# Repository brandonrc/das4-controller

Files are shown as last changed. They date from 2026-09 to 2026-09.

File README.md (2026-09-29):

# das4-controller

An open-source replacement controller board for the **Das Keyboard 4 Professional**:
same outline, same holes, same connectors, but with an **RP2350B** you can flash
with your own firmware (pico-sdk today, KMK/CircuitPython, QMK once it supports the RP2350B). It keeps the two USB-A ports (as a USB 2.0
hub), the volume knob, the NUM/CAPS/SCROLL LEDs (now RGB, any colour) and the five buttons. Every
button gets its own GPIO, so you can make them do whatever you like.

> **Status: ready to order after a final 1:1 fit print.** Routed, DRC clean (0 unconnected, 0 real
> violations), with independent circuit and layout reviews, a check against Raspberry Pi's RP2350
> design guide, and a firmware build for this pinout. See [docs/plan.md](docs/plan.md).

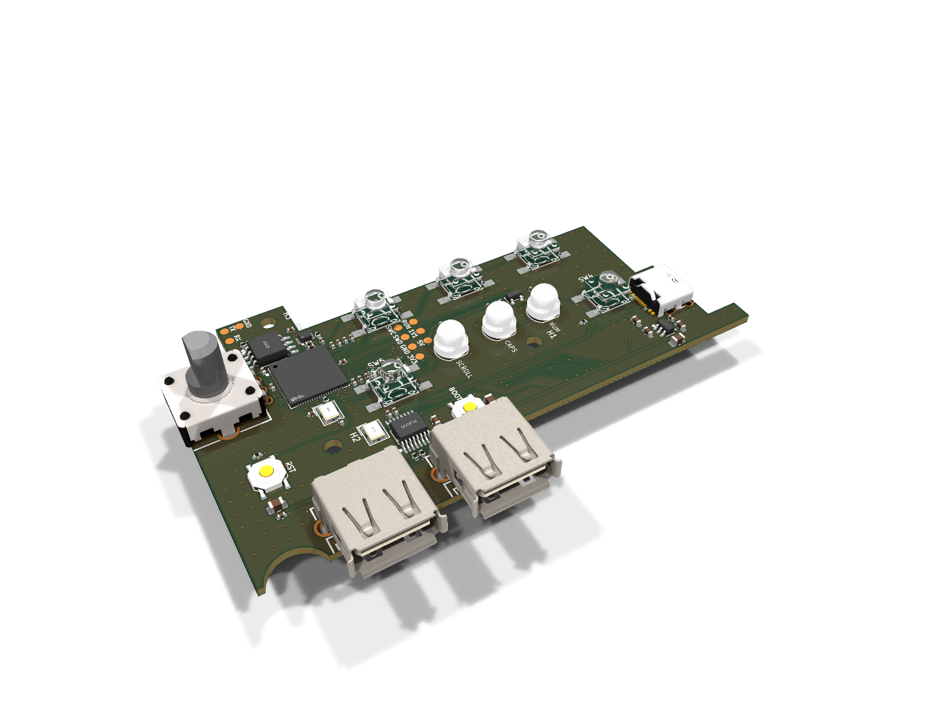
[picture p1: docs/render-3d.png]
3D render


| Top | Bottom |
|---|---|
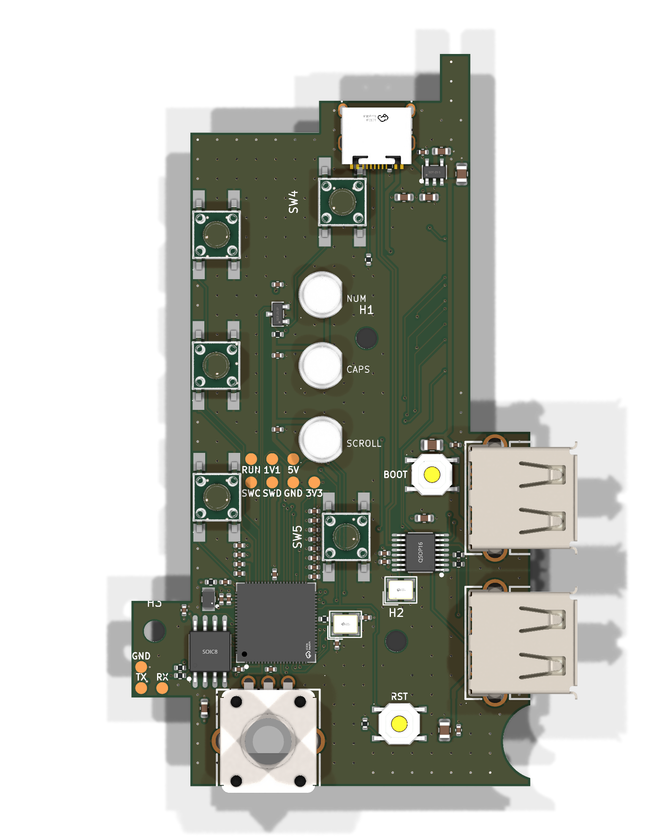
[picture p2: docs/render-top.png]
top
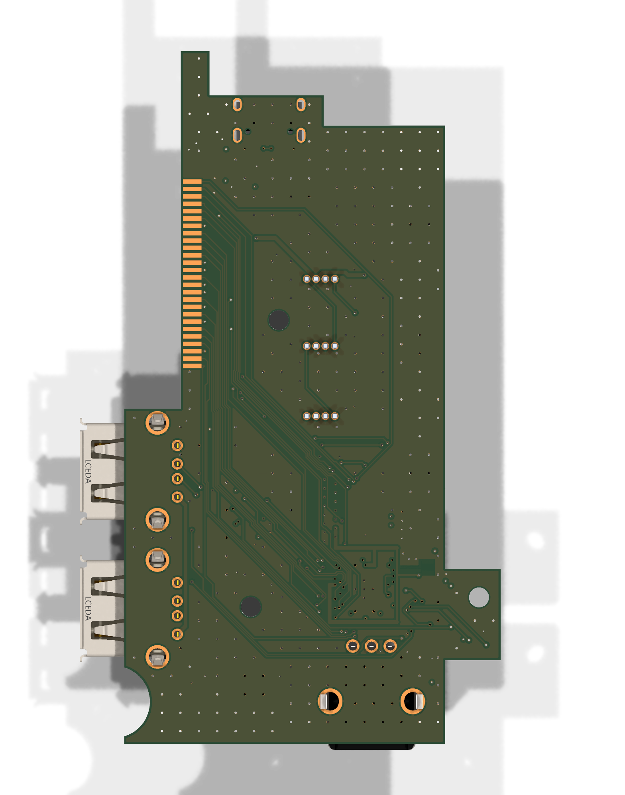
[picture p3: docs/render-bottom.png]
bottom
|  |  |

## Docs

- [Plan and status](docs/plan.md): what's done, next steps, bring-up and firmware plan
- [Design notes](docs/design.md): architecture, circuit blocks, GPIO map, ordering, open questions
- [Bill of materials](docs/bom.md): every part with its LCSC number and live JLCPCB stock
- [Measurements](docs/measurements.md): every dimension, where it came from and how sure we are
- [Fit-check PDF](docs/fit-check-1to1.pdf): print at 100% and lay the original board on it
- Reviews: [circuit](docs/review-2026-09-25.md), [layout 1](docs/review-layout-2026-09-25.md),
  [layout 2](docs/review-layout-2-2026-09-25.md), [RPi design guide](docs/rpi-guide-check-2026-09-26.md),
  [firmware](docs/firmware-check-2026-09-26.md)
- [AGENTS.md](AGENTS.md): how the pipeline works and what to watch out for (for AI agents and humans)

## Layout

```
hardware/
  circuit/das4.py                          the circuit (SKiDL)
  das4-controller.net                      netlist generated from it
  das4-controller.kicad_pro / .kicad_pcb   KiCad 10 project (board generated from the netlist)
  lib/jlc.*                                JLCPCB part symbols, footprints and 3D models (easyeda2kicad)
  lib/das4.pretty                          our own footprints (J4 flex solder pads)
  scripts/gen_board.py                     outline, measured positions, placement, silkscreen
  scripts/critical.py                      hand-drawn critical nets + keep-outs (RP2350 regulator, USB pair, crystal...)
  scripts/route.py, route_best.py          autorouting (Freerouting) + cleanup + GND stitching, best of 6 runs
  scripts/pretest.py, check_layout.py      pre-route DRC of the hand layout; post-route checks
  scripts/jlc_fab.py                       JLCPCB gerber zip, BOM and CPL
  scripts/jlc.py                           search JLCPCB's parts library (no login)
  scripts/bom.py                           docs/bom.md with live stock
docs/                                      notes, plan, reviews, renders, fit-check print
firmware/bringup/                          pico-sdk + TinyUSB bring-up firmware for this pinout
```

## Building

The tools come from the KiBot/KiCad container
[`ghcr.io/inti-cmnb/kicad10_auto_full`](https://github.com/INTI-CMNB/kicad_auto),
which is also what CI runs.

```sh
# one-time: create the container
distrobox create --name pcb --image ghcr.io/inti-cmnb/kicad10_auto_full:1.9.1-1_k10.0.5_d13.2_b4.2.4LTS

distrobox enter pcb -- make pretest       # quick DRC of just the hand layout (run before routing)
distrobox enter pcb -- make board route   # circuit -> netlist -> placed board -> autorouted (~25 min)
distrobox enter pcb -- make check         # post-route checks DRC can't do
distrobox enter pcb -- make docs drc fab  # renders, fit-check PDF, DRC, JLCPCB files (don't rebuild the board)
distrobox enter pcb -- make bom      # refresh docs/bom.md with live JLCPCB stock
```

Or use Docker directly:
`docker run --rm -v $PWD:/w -w /w ghcr.io/inti-cmnb/kicad10_auto_full:1.9.1-1_k10.0.5_d13.2_b4.2.4LTS make`.

Open `hardware/das4-controller.kicad_pro` in KiCad 10 to look around.

**Note:** the board file is *generated*: `make board` rebuilds it (unrouted)
from the circuit and `gen_board.py`, and `make route` routes it. Edit those,
not the .kicad_pcb, or your changes get overwritten.

## Ordering (JLCPCB)

```sh
distrobox enter pcb -- make fab     # -> build/jlcpcb/: gerber zip, bom.csv, cpl.csv
```

1. On jlcpcb.com upload the gerber zip. Pick **4 layers**, 1.6 mm, and the **JLC04161H-7628** stackup with impedance control.
2. Enable **PCB Assembly** (top side), upload `bom.csv` and `cpl.csv`, and check the placement preview:
   rotations, and L1's white dot on the +1V1 pad next to C165 (details in [docs/design.md](docs/design.md#ordering-at-jlcpcb)).
3. Order the "You solder" parts in [docs/bom.md](docs/bom.md) from LCSC (they can ship together).

`make fab` names the zip `...-UNROUTED-quote-only` if the board has no traces yet.

## License

MIT, see [LICENSE](LICENSE). Not affiliated with Das Keyboard / Metadot.

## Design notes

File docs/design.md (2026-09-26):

# Design notes

## Goal

A drop-in replacement for the **Das Keyboard 4 Professional** controller board
(original: `HK-D4215-2-10-03`, 2021-07-27), using an open, reprogrammable MCU.
It must keep the same outline, mounting holes and connector positions, so it
fits the stock case and the stock key-matrix cable.

## What the original board has

| Ref (orig.) | Part | Keep? |
|---|---|---|
| U4 | ~80-pin LQFP MCU, markings removed, 12 MHz crystal | **Replace** with RP2350B |
| U3 | VIA Labs (VLI) USB 3.0 hub | **Replace** with a USB 2.0 hub |
| J5 | USB-C, upstream to the PC | Keep (position) |
| J2, J3 | USB 3.0 Type-A | Keep (position), USB 2.0 is fine |
| J4 | 26-way 1.0 mm flex cable ("CON2") to the key-switch PCB, soldered on (bottom side) | Keep: solder pads, no connector |
| P1 | Rotary encoder, no push switch, 20 detents (5 per quarter turn) | Keep |
| SW1–SW5 | Tact switches | Keep, each on its own GPIO |
| NUM / CAPS / SCROLL | 5 mm THT LEDs | Keep |
| GND/CLK/DIO/5V pads | SWD programming header for U4 | Replace with our own SWD pads |

## Architecture

```
PC ──USB-C──► USB 2.0 hub ──► USB-A port 1
                         ├──► USB-A port 2
                         └──► RP2350B (USB HID keyboard + media keys)
                                 ├─ 26 × key matrix (J4)
                                 ├─ encoder A/B
                                 ├─ 5 × buttons
                                 └─ 3 × RGB lock LEDs (one data line)
```

The PC has to connect to the **hub**, and the MCU hangs off one of the hub's
downstream ports. If the PC plugged into the MCU instead (for example, a
dev board's own USB-C), the USB-A ports would have nowhere to get data from.

## GPIO budget

| Function | Pins |
|---|---|
| Key matrix via J4 (if all 26 are matrix lines) | 26 |
| Encoder: A, B | 2 |
| Buttons | 5 |
| Lock LEDs | 3 |
| **Total** | **36** |

- Seeed XIAO: 11 GPIO, so it doesn't fit.
- Raspberry Pi Pico / Pico 2: 26, so it doesn't fit without an expander.
- **RP2350B: 48, so everything fits on one chip with spare pins.**

The USB hub IC has to be factory-assembled anyway, since it only comes as a
tiny SMD part. So the whole board is factory-assembled (e.g. JLCPCB PCBA)
with a bare RP2350B, not a hand-soldered module.

Fallback: a Pico 2 module plus a 16-bit I²C expander (e.g. TCA9555) for the
buttons and LEDs.

## Circuit

The circuit is code: [`hardware/circuit/das4.py`](../hardware/circuit/das4.py)
([SKiDL](https://github.com/devbisme/skidl)). `make` turns it into a netlist and
places it on the board. The full parts list with live stock is in [bom.md](bom.md).

| Block | Part | Notes |
|---|---|---|
| MCU | RP2350B (QFN-80) | Copied from Raspberry Pi's minimal design: 12 MHz ABM8-272-T3 crystal (15 pF, 1 kΩ), 16 MB W25Q128JV flash, 3.3 µH AOTA-B201610S3R3 inductor for the on-chip 1.1 V regulator (pad 1 to +1V1), 33 Ω/4.7 µF on VREG_AVDD, 100 nF on every IOVDD/DVDD pin. USB series resistors are 22 Ω (JLCPCB Basic) instead of RPi's 27 Ω |
| USB hub | WCH CH334R (QSOP-16) | 4-port USB 2.0, built-in pull-ups/downs. Powered from 3.3 V on both V5 and VDD33 (datasheet §6.1). 12 MHz crystal with no load caps (they're on-chip). Port 1 → USB-A 1, port 2 → USB-A 2, port 3 → RP2350B, port 4 unused |
| 3.3 V | ME6211C33 LDO, 500 mA | ~0.1 V dropout and stable with ceramic caps. An AMS1117 (Basic) was tried and rejected in review: it drops out when VBUS sags on hot-plug, browning out the hub and MCU |
| USB-C | HRO TYPE-C-31-M-12 | 5.1 kΩ on CC1/CC2 (we're a device). No separate ESD chip: the CH334R has 6 kV ESD protection on all its USB pins |
| USB-A ×2 | SHOU HAN AF 90 WJDG (**hand-soldered**) | USB 2.0, right angle, through-hole. VBUS straight from the PC's 5 V (its port limits current); 22 µF + 100 nF per port |
| Encoder | Alps EC12E24204A2 (**hand-soldered**) | 12 mm, no switch, 24 detents, 15 mm D-shaft. A push switch can't fit: the body sits flush with the board edge, so switch pins would land off the board |
| Buttons ×5 | 6 × 6 × 5 mm SMD tact (**hand-soldered**) | Other heights (4.3–10 mm) exist in the same footprint if the case needs them |
| Lock LEDs ×3 | WS2812D-F5 5 mm THT **RGB** (**hand-soldered**) | Any colour from firmware. One GPIO drives the chain NUM → CAPS → SCROLL through a 2N7002 + 1 kΩ pull-up to 5 V (Basic parts): a 5 V-level signal, **inverted**, so firmware inverts the GPIO44 pad output (one register setting; see [firmware-check-2026-09-26.md](firmware-check-2026-09-26.md)). 100 nF per LED |
| BOOTSEL / RESET | TS-1187A 5 × 5 mm SMD tact (JLCPCB Basic) | BOOTSEL via 1 kΩ on QSPI_SS; RESET pulls RUN low through 1 kΩ |
| Test pads | 10, labelled | SWD (SWC, SWD, GND, 3V3, RUN), rails (1V1, 5V), and a UART0 debug console on the left tab (TX = GPIO0, RX = GPIO1, GND) |
| J4 | 26 solder pads, 1.0 mm pitch, 0.6 × 2.5 mm, bottom side at the board edge | The key PCB's flex cable is hot-bar soldered at both ends (no connector), so it's soldered straight onto these by hand, like the original. No part, no cost |

### GPIO map

Picked for routing. Any GPIO can do any job, so firmware just follows this
table ([`das4.py`](../hardware/circuit/das4.py) has the same thing).

| Function | GPIO |
|---|---|
| J4 pin *k* (key matrix) | GPIO(40 − *k*): pin 1 → GPIO39 … pin 26 → GPIO14. Follows the package pin order so the bus fans out without crossings; all on 5 V-tolerant GPIO0–39 |
| SW1 / SW2 / SW3 / SW4 / SW5 (active low, use internal pull-ups) | GPIO45 / 46 / 47 / 43 / 42 |
| Encoder A / B (internal pull-ups) | GPIO13 / GPIO8 |
| RGB LED data (WS2812, chain NUM → CAPS → SCROLL; **inverted**) | GPIO44 |
| UART0 debug console (test pads on the left tab) | GPIO0 TX / GPIO1 RX |
| Spare | GPIO2–7, GPIO9–12, GPIO40–41 |

GPIO40–47 are the ADC pins and aren't 5 V tolerant, which is fine for the
buttons and the LED driver (all 3.3 V). Mind RP2350 erratum E9 on those pins:
use the internal pull-ups, don't rely on pull-downs.

### Board

Stackup: F.Cu signals · In1 solid GND · In2 solid +3V3 · B.Cu signals + GND pour.

The MCU corner follows Raspberry Pi's minimal-design layout, drawn by hand in
[critical.py](../hardware/scripts/critical.py) and locked before autorouting:
- the core regulator block right at pins 61–65: VREG_VIN and +1V1 caps
  against the pins, LX running out between their pads into L1, GND vias
  beside them, and the VREG_AVDD RC filter
- 5 GND vias in the exposed pad, with the solder paste split into 4 windows
  (~50 %) between them so no paste sits over a via
- a via straight inward from every +3V3 pin (to the In2 plane) and every
  +1V1 pin (to a 0.5 mm +1V1 "C" on B.Cu around the chip, like RPi's)
- 100 nF caps in columns beside the pins, with a shared GND via between each
  pair; DVDD pin 10's cap right under the pin
- the crystal right beside XIN/XOUT, with XOUT's series resistor in line and no
  vias or other signals near it
- USB upstream D+/D− as a coupled pair from J1 to the hub over solid GND, kept
  more than 3 mm from the mounting hole; the CC pull-downs
- each tact switch's internally-connected pad pairs joined

Keep-outs (rule areas, from layout review 2):
- no copper on In1, In2 or B.Cu under L1 and VREG_LX (RP2350 datasheet 6.3.8)
- no top-layer pour round the regulator block, so its GND joins main GND at
  one point (the CIN/COUT via pair)
- no top-layer tracks or vias under the USB-A shells
- nothing within 2.5 mm of the mounting holes (screw heads)
- while autorouting only: nothing else through the crystal block

Then Freerouting does the rest (`make route`,
[route.py](../hardware/scripts/route.py)): 4 differently-configured runs in
parallel, best kept. After autorouting: GND stitching vias wherever the outer
pours filled, extra vias into any via-less pour piece, then fill.
Result: 921 track segments, 457 vias; 0 unconnected, 0 non-cosmetic DRC violations.

- **4 layers** (signal / GND / power / signal). The hub's upstream link runs
  at USB high speed (480 Mbit/s) and needs 90 Ω pairs over a solid ground
  plane. The inner layers also make it much easier to fan out the RP2350B's
  0.4 mm pads. At JLCPCB a small 4-layer board costs a few dollars more than
  2-layer.
- **Everything assembled on the top side**, so JLCPCB assembly is
  single-sided. That makes the MCU corner tight: the original put its MCU on
  the back.
- Design rules match JLCPCB 4-layer capabilities with margin (0.1 mm
  clearance, 0.15 mm tracks, 0.5/0.25 mm vias; 0.4/0.2 mm for the vias under
  the MCU).

## Firmware

Checked 2026-09-26 ([firmware-check-2026-09-26.md](firmware-check-2026-09-26.md)):
- **pico-sdk + TinyUSB**: supports everything today. A bring-up firmware for
  this exact pinout builds to a .uf2: [firmware/bringup](../firmware/bringup).
- **KMK / CircuitPython**: works with a small custom board definition and an
  rp2pio-based inverted WS2812 driver. Good for easy hacking.
- **QMK**: no RP2350 support yet (ChibiOS pending; the one proof-of-concept
  fork can't use GPIO above 31, and this board needs up to GPIO47). Nothing
  on the PCB blocks it once support lands.

Flashing: hold BOOTSEL and reset, and the board shows up as a USB drive
(works fine behind the hub). SWD pads as a fallback. Matrix scanning drives
low and reads with pull-ups (never internal pull-downs: RP2350 erratum E9).
The buttons are plain GPIO, so any firmware can give them "fun" functions.

## Ordering at JLCPCB

Files: `make fab` writes `build/jlcpcb/`.
1. Upload `das4-controller-gerbers.zip`. Choose 4 layers, 1.6 mm, and the
   **JLC04161H-7628** stackup with impedance control (the ~90 Ω USB pair
   widths assume it). Vias go down to 0.2 mm drill; pick the matching
   "min via hole" option if the form asks.
2. Turn on PCB Assembly, top side only. Upload `bom.csv` and `cpl.csv`.
3. In the placement preview, check the rotations of U1, U2, J1, L1, Q1, U4,
   Y1 and Y2. **L1's white polarity dot must sit on the +1V1 pad, the end
   next to C165** (Raspberry Pi's layout; the "wrong way round" inductor
   upsets the core regulator). JLC's library model has the dot on pad 2,
   which is +1V1 here, so it should already be right.
4. Hand-solder parts (not in JLC's BOM): 2 × USB-A, the encoder, 3 × WS2812D
   LEDs, 5 × 6 mm tact switches. See [bom.md](bom.md). The J4 flex is
   soldered onto its pads by hand.

## Open questions

- [x] J4 type: a 26-way 1.0 mm flex, soldered at both ends (photos 2026-09-26). The lines all fan into the switch matrix; firmware maps pad *k* to a row or column (a mirrored flex just reverses the table).
- [ ] Does the key PCB have per-key LEDs or diodes? The diode direction sets the scan direction.
- [ ] Encoder: confirm 15 mm shaft / 24 detents is close enough (original: ~14 mm, 20 detents).
- [ ] J4 (for firmware, not the order): unpowered continuity checks on the key PCB: flex pads open to its ground/copper areas; press keys to map rows vs columns; diode mode to see if per-key diodes exist. The key PCB is keys only (no lights), so nothing on it drives the lines.
- [x] Cut JLCPCB fees: 6 Extended types (RP2350B, CH334R, USB-C, inductor, crystal, ME6211 LDO); 11 easy parts are hand-soldered.
- [x] Independent design review: see [review-2026-09-25.md](review-2026-09-25.md).
- [x] Route the board.
- [x] Layout reviews: [review-layout-2026-09-25.md](review-layout-2026-09-25.md), [review-layout-2-2026-09-25.md](review-layout-2-2026-09-25.md).
- [ ] USB-C: only the A4/B9 VBUS pair is wired (B4/A9 boxed in by SW4); fine since plugs tie all VBUS pins.
- [ ] Caliper pass on everything marked *photo* in [measurements.md](measurements.md).
- [ ] Case clearance under the board (bottom side: only the J4 flex now).
- [ ] Order with JLCPCB's JLC04161H-7628 stackup (impedance control), which the ~90 Ω USB pair widths assume.

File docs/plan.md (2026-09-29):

# Plan and status

Last updated 2026-09-29.

## Where we are

**The board is finished and ready to order**, pending a 1:1 fit print in the
case. It's routed, and DRC is clean (0 unconnected, 0 non-cosmetic
violations). CI checks this on every push.

## How we got here

1. **Requirements** (2026-09-24): the same outline, holes and connector
   positions as the original. RP2350B; USB 2.0 hub with 2 × USB-A plus the
   MCU; volume encoder (no push); 5 buttons on their own GPIOs; RGB lock LEDs;
   26-line key matrix.
2. **Measurements:** photos and calipers, then a fit-check print. That fixed
   the USB-A notch (9.35 × 3.5 mm) and the knob position. See
   [measurements.md](measurements.md).
3. **Circuit as code:** SKiDL in `hardware/circuit/das4.py`, with parts
   picked from JLCPCB's library. Extended parts were cut from 15 to 6 to keep
   the order cheap.
4. **Circuit review:** [review-2026-09-25.md](review-2026-09-25.md).
5. **Placement and routing:** generated placement plus Freerouting.
   - First routed board: e51b12c.
6. **Layout review 1:** [review-layout-2026-09-25.md](review-layout-2026-09-25.md).
   - The MCU corner was redone after Raspberry Pi's minimal design: U1
     rotated, the critical nets hand-drawn in `critical.py`, In2 turned into
     a solid 3.3 V plane.
   - Commit 16007bf.
7. **Layout review 2:** [review-layout-2-2026-09-25.md](review-layout-2-2026-09-25.md).
   - Added keep-outs (under L1/LX, the USB-A shells, the screw heads, the
     crystal).
   - DVDD caps, a windowpane paste pattern on the exposed pad, and other
     fixes.
   - Commit f079e2b.
8. **J4:** the key PCB's flex cable is soldered at both ends (photos,
   2026-09-26), so J4 became 26 solder pads at 1.0 mm pitch. There's no
   connector, and the lines are keys only, with no 5 V.
9. **Checked against Raspberry Pi's "Hardware design with RP2350":**
   [rpi-guide-check-2026-09-26.md](rpi-guide-check-2026-09-26.md).
   - The circuit matches their reference.
   - A cap was added at DVDD pin 51.
   - L1's orientation was confirmed.
10. **Firmware check:** [firmware-check-2026-09-26.md](firmware-check-2026-09-26.md).
    - pico-sdk + TinyUSB builds for this pinout (`firmware/bringup`).
    - KMK/CircuitPython works with a custom board definition.
    - QMK has no RP2350 support yet.
    - UART debug pads were added on the strength of this check.

## Next steps

1. **Fit print (owner):** print `docs/fit-check-1to1.pdf` at 100 % (Actual
   size) and lay it in the case. Check the J4 pad strip against the flex, the
   USB-C/USB-A mouths, the 3 mounting holes, the knob and the buttons.
2. **Order at JLCPCB.** Follow "Ordering at JLCPCB" in [design.md](design.md):
   - 4 layers, JLC04161H-7628 stackup with impedance control
   - top-side assembly with `bom.csv` and `cpl.csv`
   - check L1's dot and the rotations in the placement preview
   - order the hand-solder parts from [bom.md](bom.md)
3. **Hand-solder:** USB-A ×2, encoder, WS2812D ×3, 6 mm switches ×5, and the
   J4 flex onto its pads.
4. **Bring-up** (see below).
5. **Keyboard firmware** (see below).

## Bring-up plan

Do it in this order, and stop at the first surprise.

1. **Before power:** look for solder bridges, especially at U1 (0.4 mm pitch)
   and the hub. Check the ohms from 5V, 3V3 and 1V1 to GND: none should be a
   short.
2. **First power**, from USB-C, ideally through a current-limited USB meter.
   Use the test pads:
   - **5V:** about 5 V
   - **3V3:** 3.3 V
   - **1V1:** about 1.1 V, from the RP2350's internal regulator
3. **The hub** should enumerate on the PC as a USB 2.0 hub. Test both USB-A
   ports with a USB stick.
4. **Hold BOOT and tap RST:** an RP2350 drive should appear. If it doesn't,
   use the SWD pads (SWC, SWD, GND) with a Raspberry Pi Debug Probe.
5. **Flash `firmware/bringup`:**
   - it should enumerate as a USB keyboard
   - the LEDs should light
   - SW1 should respond
   - a USB-serial adapter on TX/RX/GND (115200 baud) shows `printf` output
     even if USB fails
6. **Map the key matrix:** press keys and log which J4 lines connect, to get
   rows vs columns and whether the key PCB has diodes. Unpowered continuity
   checks on the key PCB work too.

## Firmware plan

1. **pico-sdk + TinyUSB keyboard**, built from `firmware/bringup`:
   - matrix scan with debounce and ghost-key handling (if the key PCB has no
     diodes), and a keymap
   - media keys on the encoder and the 5 buttons
   - lock-LED report onto the RGB LEDs (red by default, changeable)
2. **Later:** port to QMK/Vial once QMK supports the RP2350B, including
   GPIO above 31. Nothing on the PCB blocks that. KMK/CircuitPython is an
   option for easy hacking in the meantime.

## Known deviations (accepted)

- The USB 22 Ω resistors sit at the hub end, not at the RP2350. It works at
  12 Mbit/s; the guide prefers 27 Ω close to the chip.
- DVDD pin 32's nearest cap is about 11 mm away, because there's no room
  beside it.
- A few vias touch same-net pads (SW3 GND, TP8), which is harmless.
- Some footprints' own silkscreen outlines touch pads; JLC trims them.

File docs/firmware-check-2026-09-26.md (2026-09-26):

# das4-controller: firmware readiness check (2026-09-26)

## Verdict

**Yes, with caveats. No hardware change is required before ordering.**

- **pico-sdk + TinyUSB** supports every pin and feature on this board today. A test firmware using this exact pinout builds to a `.uf2` (see Build).
- **CircuitPython/KMK** also works, but it needs a small custom board definition and a custom inverted PIO LED driver.
- **QMK cannot target this board today.** It has no RP2350 support in master or develop. The only RP2350 port is an out-of-tree proof of concept, and it explicitly does not support RP2350B GPIO above 31. This board uses GPIO32–47 for 8 matrix lines, all 5 buttons and the LED.
- **No pin swap can fix the QMK problem.** The board needs 36 signals, but only 32 GPIO (0–31) exist below GPIO32.
- **One doc error to fix.** `docs/design.md` says to use QMK `WS2812_EXTERNAL_PULLUP` for the inverted LED line. That is wrong for this circuit (details in the table notes).

## Firmware options × requirements

| Requirement | pico-sdk 2.3.1 + TinyUSB | CircuitPython 10.3.1 + KMK | QMK (master/develop, 2026-09-26) | QMK POC branch `emolitor/em-rp2350` (2026-07-22) |
|---|---|---|---|---|
| RP2350B (QFN-80) | ✅ `PICO_RP2350A=0`. Stock example: `pimoroni_pga2350.h` (RP2350B + 16 MB) | ✅ `CHIP_PACKAGE = B`. Example: `adafruit_metro_rp2350` (RP2350B, W25Q128JV) | ❌ No RP2350 at all. Schema lists only `RP2040`. Issue #25881 was closed "not planned" pending ChibiOS | ⚠️ RP2350**A** pinout only |
| GPIO30–47 | ✅ `gpio_get_all64()`. PIO uses `GPIOBASE=16`, which the SDK handles automatically (`pio_claim_free_sm_and_add_program_for_gpio_range`) | ✅ `microcontroller.pin.GPIO32…47`. rp2pio computes the GPIO base | ❌ | ❌ "GPIO banks above 31 … not yet supported" |
| 16 MB flash | ✅ `PICO_FLASH_SIZE_BYTES`, `boot2_w25q080` | ✅ `EXTERNAL_FLASH_DEVICES = "W25Q128JVxQ"` | ❌ | ⚠️ `RP_FLASH_SIZE` override (default 4 MB) |
| Inverted WS2812 | ✅ Standard PIO program plus `gpio_set_outover(44, GPIO_OVERRIDE_INVERT)`. Built and verified here | ⚠️ `neopixel_write` can't invert. Use `rp2pio.StateMachine` with the ws2812 program's side-set values swapped and `initial_sideset_pin_state=1`, then pass it to KMK's RGB extension via `pixels=`. Or set OUTOVER through `memorymap` | ❌ `WS2812_EXTERNAL_PULLUP` is open-drain and **non-inverting** (side-set on pindirs). On this 2N7002 gate it would leave the LEDs stuck. You'd have to patch in `PAL_RP_IOCTRL_OUTOVER_DRVINVPERI` | ❌ (pins) |
| Encoder (GPIO13/8, pull-ups) | ✅ Write it yourself (quadrature state table) or use a PIO quadrature example | ✅ `kmk/modules/encoder.py` | (✅ on RP2040) | ❌ (pins ≥32 elsewhere) |
| 26-line matrix + direct pins | ✅ Write it yourself (example included). 26 lines fit in one `gpio_get_all64()` read | ✅ `keypad.KeyMatrix` / KMK `keypad` scanner. **Pass the anode-side lines as columns and keep `columns_to_anodes=True`**: `False` switches to pull-downs, which E9 affects | (✅ on RP2040) | ❌ |
| UF2 / BOOTSEL | ✅ ROM bootloader. `picotool reboot -f -u` via `pico_usb_reset_interface` | ✅ | ❌ | ✅ `bootloader: rp2350`, `QK_BOOT` |

**Recommendation: pico-sdk + TinyUSB now.**
- It's the only path that fully covers RP2350B today, and it has already been built here.
- A keyboard is roughly 500 lines on top of the test firmware: matrix, debounce, keymap, HID with NKRO and consumer keys, lock-LED output report, encoder.
- CircuitPython/KMK is a good second choice for quick hacking. It supports the chip; it just needs a board definition without the Metro's status NeoPixel on GPIO25 and PSRAM chip-select on GPIO47 (both are pins this board uses) and the inverted LED driver.
- Move to QMK/Vial once QMK adds RP2350B GPIOBASE support. Nothing on the PCB blocks that; it's purely a software gap.

## Flashing and bring-up

- **BOOTSEL wiring is correct.** It's QSPI_SS → 1 kΩ → button → GND, with a 10 kΩ pull-up (about 0.3 V when pressed), the same as RPi's reference.
  - The bootrom enters BOOTSEL when QSPI CSn is low at reset (datasheet §5.2).
  - It picks USB rather than UART boot because QSPI SD1 is not driven high. SD1 has a default pull-down, and the W25Q128 DO pin is high-Z with no command.
  - Hold BOOTSEL, press RUN, and it enumerates as the RP2350 UF2 drive / picotool device.
- **Behind the CH334R hub: no issue.**
  - The RP2350 is a full-speed device. The CH334R is a multi-TT high-speed hub, so the FS device is handled by the hub's transaction translator, which is normal.
  - The ROM bootloader and TinyUSB don't care about a hub.
  - The RP2350 has no VBUS pin; the SDK and TinyUSB force VBUS-detect in software.
  - After the first flash, the BOOTSEL button isn't needed: `picotool reboot -u`, or a firmware key calling `rom_reset_usb_boot()`, gets back to the bootloader.
- **SWD is a usable fallback.** Pads TP1–TP5 (SWCLK, SWDIO, GND, 3V3, RUN) work with a Raspberry Pi Debug Probe or a Pico running debugprobe, plus RPi's OpenOCD fork (`target/rp2350.cfg`, full support) or upstream OpenOCD master (Arm cores).
- **12 MHz** is the SDK default: `XOSC_HZ 12000000` in `rp2350/.../platform_defs.h`. The bootrom's USB PLL also assumes 12 MHz unless OTP says otherwise (datasheet §5.2).
- **Board header needed** (`boards/das4_controller.h`, modelled on `pimoroni_pga2350.h`):
  - `PICO_RP2350A 0`
  - `PICO_FLASH_SIZE_BYTES (16*1024*1024)`
  - `PICO_BOOT_STAGE2_CHOOSE_W25Q080 1`
  - `PICO_FLASH_SPI_CLKDIV 2`
  - `PICO_PLATFORM rp2350` (arm-s)
  - As a shortcut, `-DPICO_BOARD=pimoroni_pga2350` also works as-is. The RP2350 has no separate boot2 stage like the RP2040; the SDK embeds an IMAGE_DEF block for the bootrom.

## Build attempt: succeeded

The host had git and g++ but no cmake or arm-none-eabi-gcc (the `pcb` distrobox has neither). Everything was installed in the scratchpad in about 5 minutes:

```sh
cd scratchpad/fw
python3 -m venv venv && ./venv/bin/pip install cmake ninja        # cmake 4.4.3
git clone --depth 1 https://github.com/raspberrypi/pico-sdk.git   # SDK 2.3.1 (079c6f3, 2026-09-04)
git -C pico-sdk submodule update --init --depth 1 lib/tinyusb
curl -L https://developer.arm.com/-/media/Files/downloads/gnu/15.2.rel1/binrel/arm-gnu-toolchain-15.2.rel1-x86_64-arm-none-eabi.tar.xz | tar xJ
./build.sh     # PICO_SDK_PATH/PICO_TOOLCHAIN_PATH; cmake -G Ninja; ninja  (picotool auto-fetched and built)
```

Result: `fw/build/das4fw.uf2` (39 KB), 0 warnings. `picotool info -a` reports family `rp2350-arm-s`, `pico_board: das4_controller`, `boot2_w25q080`, SDK 2.3.1. Compile-time asserts check `NUM_BANK0_GPIOS == 48` and `PICO_FLASH_SIZE_BYTES == 16 MB`.

What the test firmware (`fw/das4fw/`) does:
- Enumerates as a TinyUSB HID keyboard.
- Scans an 8×18 placeholder split of GPIO14–39: drives lines low one at a time and reads the others with pull-ups.
- Reads SW1 on GPIO45 (pull-up) and sets pull-ups on the encoder pins GPIO13/8.
- Drives 3 × WS2812 on GPIO44 with the standard PIO program and pad-level output inversion. PIO idles low, so the pad sits high, the FET is on, and DIN is held low (the WS2812 reset state).

Not tested on hardware (there is no board yet).

## Hardware checks

- **E9 (datasheet build 2025-07-29, p.1366):**
  - What it is: on **A2** silicon, an input-enabled pad sitting between VIL and VIH leaks about 120 µA and latches near 2.2 V, which beats the internal pull-down. Pull-ups work normally.
  - Status: fixed in A3/A4 silicon ("Fixed by RP2350 A3"). The workaround is to avoid internal pull-downs, or use an external pull-down of 8.2 kΩ or less.
  - JLC's C42415655 (4,271 in stock) doesn't state the stepping. The design doesn't depend on it; at runtime, `rp2350_chip_version()` reports it.
  - Matrix: always scan by driving low and reading with pull-ups. With diodes, drive the cathode-side lines and read the anode side; either diode direction can be scanned this way, so the unknown row/column split doesn't matter. Without diodes, E9 isn't a factor either, but ghosting is: firmware must block ghosts.
  - Buttons (pull-ups, active low) and encoder (common to GND, pull-ups): unaffected.
  - The LED gate relies on the power-on pull-down, which E9 doesn't affect: it only applies once IE is set, and firmware drives the pin by then.
- **ADC pins as digital inputs:** GPIO40–47 are ordinary digital I/O that also have the ADC. Digital input works once `gpio_init` sets IE and clears ISO; the SDK and CircuitPython do this. Just don't enable their ADC channels. They are **not** 5 V tolerant (VPIN ≤ IOVDD + 0.5 V), and nothing on them exceeds 3.3 V: buttons to GND, and the 2N7002 gate.
- **5 V tolerance:** J4 is on GPIO14–39, which are FT pins (up to 5.5 V with IOVDD at 3.3 V). The key PCB is passive, so it's moot anyway.
- **LED level shifter timing:** the 1 kΩ pull-up with about 40 pF gives about 50 ns to reach 0.7·VDD. That shortens each DIN high pulse by about 50 ns. A 0-bit is then about 325 ns high, still inside WS2812D T0H (220–380 ns). Fine.

## Hardware changes before ordering

**Required: none.**

Optional, cheap, and useful:
1. **Put GPIO0/GPIO1 (spare, UART0 TX/RX) on two test pads.** This gives a debug console during bring-up that doesn't depend on USB enumeration. It's the only change I'd actually make.
2. **Only if you want unpatched QMK/KMK LED drivers someday:** replace the 2N7002 + 1 kΩ inverter with a non-inverting 5 V buffer, e.g. 74AHCT1G125 (VCC 5 V, OE to GND). Not needed: pad inversion is one register write in every framework.

Doc fix (not hardware): in `docs/design.md`, replace "QMK: `WS2812_EXTERNAL_PULLUP`" with "invert the pad output (`IO_BANK0 GPIO44_CTRL.OUTOVER = INVERT`)". Also note that QMK doesn't yet support RP2350B.

## Sources (fetched 2026-09-26)

- RP2350 datasheet, build-date 2025-07-29: E9 p.1366–1367, A3 changes, pin types/FT §14.8.2, BOOTSEL/UART boot §5.2/§5.8. https://datasheets.raspberrypi.com/rp2350/rp2350-datasheet.pdf
- A4 stepping / E9 fix: CNX Software 2025-07-29, https://www.cnx-software.com/2025/07/29/raspberry-pi-rp2350-a4-stepping-fixes-e9-gpio-erratum-9-glitching-bugs-introduces-2mb-flash-variants/ ; Hackaday 2025-07-31, https://hackaday.com/2025/07/31/raspberry-pi-rp2350-a4-stepping-addresses-e9-current-leakage-bug/
- pico-sdk 2.3.1 (2026-09-04): https://github.com/raspberrypi/pico-sdk (`pimoroni_pga2350.h`, `hardware_pio` GPIOBASE, `platform_defs.h`)
- QMK master b1aea25 / develop 5060d75 trees (2026-09-26), no RP2350 files: https://github.com/qmk/qmk_firmware ; issue #25881 (comments to 2026-07-22): https://github.com/qmk/qmk_firmware/issues/25881 ; QMK `ws2812_vendor.c` (develop): https://github.com/qmk/qmk_firmware/blob/develop/platforms/chibios/drivers/vendor/RP/RP2040/ws2812_vendor.c
- QMK RP2350 POC `docs/platformdev_rp2350.md` (2026-07-22): https://github.com/emolitor/qmk_firmware/blob/em-rp2350/docs/platformdev_rp2350.md
- ChibiOS RP2350 commit 532dcc8 (2026-01-18); latest tag still ver21.11.5: https://github.com/ChibiOS/ChibiOS
- CircuitPython 10.3.1 (2026-09-14); `rp2pio/StateMachine.c` GPIO-base handling; `adafruit_metro_rp2350` board; `shared-module/keypad/KeyMatrix.c`: https://github.com/adafruit/circuitpython ; rp2pio docs: https://docs.circuitpython.org/en/latest/shared-bindings/rp2pio/index.html
- KMK main (2026-04-09): `kmk/extensions/rgb.py` (`pixels=`), `kmk/modules/encoder.py`: https://github.com/KMKfw/kmk_firmware
- OpenOCD RP2350: https://github.com/raspberrypi/openocd/blob/sdk-2.0.0/tcl/target/rp2350.cfg ; https://review.openocd.org/c/openocd/+/8449
- JLCPCB part C42415655 stock (API, 2026-09-26): https://jlcpcb.com/partdetail/C42415655
- Arm GNU Toolchain 15.2.rel1: https://developer.arm.com/downloads/-/arm-gnu-toolchain-downloads

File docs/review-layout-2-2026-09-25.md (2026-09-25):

# Layout review 2: das4-controller (board as of 16007bf, 2026-09-25)

Method: I copied the board to the scratchpad, refilled the zones, and ran pcbnew scripts plus kicad-cli DRC. I rendered each layer and checked the regulator section against the RP2350 datasheet (section 6.3.8, "External components and PCB layout requirements") and "Hardware design with RP2350". Coordinates are board mm (origin 100,150, +Y up).

DRC: 0 unconnected. 6 errors: 3 starved thermals (Y2.2, Y2.4, J2.4 on B.Cu), and 3 malformed courtyards on D1–D3, which means those three LEDs are silently left out of the courtyard-overlap check. 59 silkscreen warnings.

## Verdict: **fix first**

The MCU corner rework dealt with most of the first review. Three things still stop this going to the fab:
- J4 is still a placeholder.
- The regulator ignores a "must" in the RP2350 datasheet: the inner planes run solid under L1 and VREG_LX.
- VBUS and key-matrix traces run under the grounded USB-A shells.

Everything else is cheap to fix while you're in there.

## Previous review: status

| # | Finding (review 1) | Status | Evidence now |
|---|---|---|---|
| B1 | EP has no GND vias | **Resolved** | 3×3 array of 0.5/0.25 vias in U1.81, straight into the solid In1 |
| B2 | Regulator ignores RPi layout | **Partial** | C164 (CIN) is 1.2 mm from pins 64 and 62. C165 (COUT) is next to L1.2 (1.8 mm). FB is a Kelvin tap at C165+ (2.8 mm), not under L1. C161 has its own GND via. **But** there's no plane cut-out under L1/LX, RUN runs under L1, and LX is a 0.15 mm trace under the L1 body (see Blockers) |
| B3 | USB_UP not a pair | **Resolved** | Coupled on F.Cu, 0.25/0.15 mm, ≈86–90 Ω on JLC04161H-7628 once solder mask and the 0.25 mm coplanar pour are allowed for. Centreline over solid In1 the whole way. Only vias are the D− hop at J1. D+ 56.0 mm vs D− 54.5 mm (≈10 ps). At least 3.2 mm from H1 |
| B4 | J4 is a placeholder | **Not resolved** | Still `PinSocket_1x26_P1.00mm_Vertical` on B.Cu; design.md says pitch and type are unknown |
| S | +3V3 only on 0.15 mm traces | **Resolved** | In2 +3V3 is one piece covering 81 % of the board (In1 GND covers 90 %) |
| S | MCU decoupling 7–14 mm away | **Partial** | Pins 5, 41, 59, 60 and 64 have caps right at the pin. IOVDD pins 15, 24, 29, 50, 68, 69 and 76 reach their caps only through a via, the In2 plane and 8–20 mm of distance. DVDD pins 10, 32 and 51 are 15.5, 24 and ≈12 mm of trace from the nearest +1V1 cap |
| S | USB_MCU_D− 0.1 mm from L1 | **Resolved** | USB_DP/DM now leave inward and run on B.Cu under the chip |
| S | Y1 crystal traces long | **Partial** | XIN is 4.9 mm and XOUT 6.4 mm, no vias. **But** the autorouter put KM18 through C230's and C231's pad gaps, and KM15/KM16 vias sit 0.2–0.5 mm from XIN/XOUT (see Should fix) |
| S | +5V 0.3 mm | **Resolved** | 0.5 mm everywhere (0.375 mm into C12). About 50 mΩ from J1 to J2, 70 mΩ to J3 |
| S | Vias inside pads | **Partial / worse** | Now 22 vias touch pads: 20 shared decoupling GND vias each overlap two 0402 pads by 0.01 mm; Y1.2 by 0.05 mm, Y2.2/Y2.4 by 0.09 mm, L1.2 is 0.008 mm off the pad; plus 9 open vias in the EP |
| S | Hub decoupling far; GND pin 14 on 0.112 mm | **Partial** | C6/C7 are within 1.5 mm of pins 12/13, but connect through plane vias rather than directly. Pin 14 still leaves on a 0.112 mm neck, though pour spokes now also reach it |
| S | USB_A1 under J2's shell, pair splits layers | **Not resolved** | Each line still has a via to B.Cu. On B.Cu the two lines are 1.4 mm apart (uncoupled, ≈125 Ω diff) and referenced to the 3V3 plane. Mismatch 3.4 mm (D− 11.5, D+ 8.1); D− hooks round the D+ via at (33.1–33.9, 35.5) |
| N | Single-spoke thermals | Partial | Y2.2, Y2.4 and J2.4 (B.Cu) are starved |
| N | Silkscreen | Not | 23 silk-over-copper. The **U1** label sits on U3 (2.1, 21.0), **U3** on L1, **L1** over U1 pins 62–65, **Y2** over U2 pins 12/13, **TP1** over TP5 |
| N | WS2812 pads 1.27 mm / 0.22 mm gap | Not | Footprint unchanged |
| N | Define the JLC stackup | Not | The .kicad_pcb has no `(stackup)` section |
| N | USB-C VBUS/GND pads 0.1 mm apart | Not | Footprint unchanged (stock HRO footprint; acceptable) |

## New findings

### Blocker

1. **Solid planes under L1 and VREG_LX, and a signal under L1** (L1 at 2.34, 24.0)
   - **What the datasheet says** (§6.3.8.1): "For a multi-layer board (4 or more layers) please cut away any copper immediately underneath L/VREG_LX". It also says to cut copper under the inductor on the top layer, and that "these guidelines must be strictly followed".
   - **What I measured:**
     - In1 GND is 96 % filled under the L1 body and 100 % under the LX strip. In2 +3V3 is 93 % and 100 %.
     - RUN runs on B.Cu at x = 1.9–2.3 mm, from y 19.1 to 30.2, i.e. right under L1.
     - The +1V1 spine on B.Cu (x = 3.2 mm, 0.5 mm wide) also runs under L1.
   - **Fix:**
     - Add a keep-out rule area (tracks, vias, pours) on In1, In2 and B.Cu covering L1 plus about 0.3 mm, and the LX trace from pin 63 to L1.1.
     - Move RUN out of that area. The +1V1 spine can start at the via (3.35, 22.35) heading away from L1.
     - After the change, check the In2 3V3 path to pin 64 still exists.

2. **J4 footprint unknown** (carried over): don't order until the connector pitch, type and position are confirmed. The 26 key-matrix nets are the board's reason to exist.

3. **VBUS and key-matrix traces under the USB-A metal shells**
   - **Measured:** F.Cu length inside the J3 courtyard: **+5V 13.5 mm** (x = 37.49, y 16–22.6, between the pin row and the shell tabs). Inside J2: KM26 13.4 mm, KM23 11.1 mm, +5V 4.0 mm.
   - **Risk:** the shell is GND and sits on the solder mask. One scuff shorts the host's VBUS to GND, or a matrix line to GND.
   - **Fix:** keep-out on F.Cu over both shell footprints (x > 35.4 inside the J2 and J3 courtyards). Route +5V from J2.1 to J3.1 on B.Cu, on the x < 35.3 side. Move KM23 and KM26 off that area.

### Should fix

1. **DVDD decoupling and the second 4.7 µF**
   - **Measured:** 100 nF caps C110, C132 and C151 sit in a column at x = 15.9, y 28–30. Trace paths from DVDD pins 10, 32 and 51 are about 32, 24 and 12 mm, much of it the 0.5 mm B.Cu spine. C166 (the second COUT) is 25–35 mm of trace from every DVDD pin.
   - **Guidance:** RPi wants 100 nF at every power pin, and the second 4.7 µF "on the bottom edge of the package", away from LX/COUT.
   - **Fix:**
     - Put a 100 nF at pin 10 (≈10.8, 15.2; there's a 1.4 mm strip between U1 and the ENC1 courtyard) with C166 beside it.
     - Put one at pin 32, on the right side, when rerouting around Y1.
     - Same idea for IOVDD: pins 15, 24 and 29 have no cap within 6.5 mm.

2. **Key-matrix lines through the crystal block**
   - **Measured:**
     - KM18 (F.Cu) runs at y = 18.3 between C230's pads, 0.125 mm from each.
     - It then goes up x = 22.50, between C231's pads, 0.8 mm from Y1.3.
     - The KM15 via at (17.20, 22.44) is 0.19 mm from the end of the XOUT trace; the KM16 via at (17.32, 19.99) is 0.46 mm from XIN.
   - **Fix:** F.Cu keep-out over Y1, C230, C231 and R231 plus 0.5 mm, then reroute KM18 on B.Cu (In1 shields it there).

3. **Regulator GND should join main GND at one point** (datasheet: "only connect to main GND at one point").
   - **Measured:** the C164/C165 GND pads are tied to the F.Cu pour by thermal spokes (0.19/0.15 mm² of overlap), in addition to their two vias at (3.99/4.93, 25.1).
   - **Fix:** F.Cu pour keep-out around the C164/C165/L1 block, so that CIN/COUT GND reaches main GND only through that via pair.

4. **LX trace**
   - **Measured:** 0.15 mm wide, 4.75 mm long.
   - **Route:** it runs between both caps' pads with 0.125 mm clearance, then 1 mm under the L1 body into pad 1 from below.
   - **Fix:** make it 0.3–0.4 mm and bring it into L1.1 from outside the body. Rotating or moving L1 so pad 1 faces pin 63 would make this simpler.

5. **EP paste and vias**
   - **Measured:** U1.81 paste is one 3.4 × 3.4 aperture (100 % coverage) over 9 untented, unplugged 0.25 mm vias. That means voids and solder wicking, and on a 0.4 mm pitch QFN, a risk that the part floats and opens pins.
   - **Fix:** a 2×2 or 3×3 windowpane at 50–65 % coverage that sits between the vias. Alternatively order via-in-pad epoxy-filled and capped.

6. **Vias overlapping pads**
   - **Measured:** the 20 shared GND vias in the decoupling columns (x = 16.38 and x = 5.82) each overlap two pads by 0.01 mm. That leaves a mask tent of about 0.31 mm over a 0.2 mm hole.
   - **Fix:** move each via 0.35 mm outboard of the pad ends (x ≈ 16.75 / 5.45) with a short neck. Pull the Y1.2 via at (21.90, 19.95) out to x ≥ 22.1, and the Y2 vias at (28.93, 23.71) and (25.07, 26.69) likewise.

7. **Signals under the mounting-hole screw heads**
   - **Measured:** non-GND copper 0.3–0.9 mm from the 2.7 mm hole edge.
     - H1: KM10/KM11 on B.Cu at 1.65–1.94 mm from the hole centre.
     - H2: KM13, KM21 and KM23 at 1.65–1.8 mm.
   - An M2.5 head or standoff is about 4.5–5 mm across, so these traces sit under the metal.
   - **Fix:** a round keep-out of radius 3 mm on F.Cu and B.Cu around H1–H3. A plated GND ring is optional.

8. **USB_A1**
   - **Fix:** route +5V to J2.1 on B.Cu (or from the outside). That frees F.Cu so D± can run as a coupled 0.2/0.12 pair straight to J2.2/J2.3, like USB_A2 (which is fine at ≈90 Ω, 1.5 mm mismatch). That drops both vias and the 3.4 mm skew.

### Nice to have

- **Foreign vias beside USB_UP:** the KM20 via at (26.88, 50.32) is 0.16 mm from USB_UP_D−, and its In1 anti-pad eats under the trace edge. The KM9 via at (25.27, 60.16) is 0.3 mm from D+. Move both at least 0.75 mm clear.
- **R266/R267** (22 Ω) sit at the hub, 30 mm from the RP2350. The guide says to put them "close to RP2350". It doesn't matter electrically at 12 Mbit/s, but it's the documented rule.
- **LDO:** U4.5 (+3V3) reaches the plane through a single 0.45/0.2 via at (29.75, 80.70). The output caps C4/C5 are 4–5 mm away through the planes. Add 2 more vias and put C4 right at pin 5.
- **Stackup:** add JLC04161H-7628 to the board setup and choose it (with impedance control) on the order form. Otherwise the ≈90 Ω pair widths are only an assumption.
- **Vias:** 94 vias have 0.2 mm drills. Pick JLC's matching "min via hole" option and check whether it adds cost. Everything else is well inside JLC's 4-layer limits: minimum track 0.112 mm, clearance 0.10 mm, annular ring ≥ 0.1 mm, copper ≥ 0.3 mm from the edge.
- **D1–D3 courtyards:** fix them so the courtyard checks run on the LEDs.
- **Silkscreen:** move the refdes labels listed above. Don't rely on the silk for L1's dot; confirm the polarity in JLC's DFM/placement preview. The footprint's r = 0.13 dot is at pad 2 = +1V1, as the circuit review intended.
- **Test points:** add pads for +1V1 and +5V, to check the regulator at bring-up.
- **B4A9:** the USB-C VBUS pad B4A9 is left floating. Tie it to +5V if routing allows.
- **CPL/BOM** (build/jlcpcb, which is current):
  - All 58 assembled parts are present; the hand-solder parts are correctly left out.
  - Gerbers and drill files share the aux origin (100, 150), consistent.
  - The BOM comment for SW6 reads "RESET" (it's BOOTSEL); cosmetic only.
  - Check rotations for U1 (90), U2 (90), J1 (180), L1 (270), Q1, U4 and Y1/Y2 in JLC's preview.

## Verified OK
- In1 is solid GND under every USB and crystal centreline.
- Stitching vias are about 2.5 mm apart.
- Main VREG loop: CIN at the pins and COUT at L1, both returning to PGND in about 2 mm.
- The FB Kelvin tap is not under L1.
- The VREG_AVDD RC has its own GND via.
- Flash: QSPI traces are ≤ 10 mm with only 2 vias (SD2/SD3). The pull-up and BOOTSEL resistors sit at U3.
- CC pull-downs are fine.
- USB_A2 pair is fine.
- The +5V trunk is 0.5 mm.
- The encoder frame is tied to GND.

## Follow-up (same day)

Addressed in the next commit, board re-routed: 0 unconnected, 0 non-cosmetic DRC violations in all 4 router variants.

| Finding | Done |
|---|---|
| Blocker 1: planes/signals under L1 and LX | Rule area: no copper on In1, In2 or B.Cu under L1 or along LX. The +1V1 spine now leaves under U1's left pad row, and RUN is routed elsewhere |
| Blocker 2: J4 | **Open**: waiting on the connector's pitch, type and photos |
| Blocker 3: under the USB-A shells | Rule area: no F.Cu tracks or vias under either shell |
| DVDD decoupling | C110 sits right under pin 10, with GND straight into the encoder's GND pin. Encoder moved to GPIO13 (A) and GPIO8 (B) so it doesn't cross. Pins 32 and 51 still use the cap column: no room beside them |
| Crystal block | Router-only keep-out; checked afterwards that no foreign net comes within 0.2 mm of Y1, C230, C231 or R231 |
| Regulator GND at one point | Rule area: no F.Cu pour round C164/C165/L1 |
| LX trace | Now enters L1 pad 1 from outside the body, 0.25 mm wide there. It stays 0.15 mm between the two 0402 pads (0.4 mm gap), which is Raspberry Pi's own minimal-design pattern |
| EP paste over vias | 5 vias in a "+", with paste as 4 windows between them (about 50 %) |
| Vias touching pads | Decap columns at a 1.2 mm pitch, so the shared GND vias clear both pads. Plane-fanout vias no longer touch their own pad. 2 same-net cases remain: a GND via on SW3's GND pad (hand-soldered) and the SWCLK via on test pad TP1 |
| Screw heads | Rule area: nothing within 2.5 mm of H1, H2 or H3 on F.Cu or B.Cu (4.5 mm pan head plus 0.25 mm) |
| USB_A1 | Router's choice (the shell keep-out now stops F.Cu under the shell) |
| Nice-to-haves | Not done yet: USB_UP foreign vias, R266/R267 placement, extra LDO output vias, stackup definition, D1–D3 courtyards, silkscreen refdes, +1V1/+5V test pads, B4A9 |

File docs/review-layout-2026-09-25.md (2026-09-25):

# Layout review, 2026-09-25

Same setup as the [circuit review](review-2026-09-25.md): an independent
reviewer measured the routed board (commit e51b12c) with pcbnew scripts.
Connectivity was clean (0 unconnected, DRC clean apart from cosmetics); the
findings are about **layout quality**, i.e. what the autorouter did badly.

## Blockers
1. **RP2350B exposed pad (U1.81, the only GND pin) has no GND vias**: it
   reaches ground through a 0.15 mm trace, PGND, one 0.45 mm via and a
   14 mm² F.Cu island. Needs a via array into In1.
2. **Core regulator layout ignores RPi guidance**: nearest cap to VREG_VIN
   (pin 64) is 20 mm away by trace; +1V1 runs 25 mm from L1 before its first
   cap; the 4.7 µF output caps are 44 mm away through 3 vias; VREG_FB is 35 mm
   from L1.
3. **USB_UP_D± (480 Mbit/s) not routed as a pair**: D+ on B.Cu, D- on
   F.Cu/In2, about 2 mm apart. The B.Cu side's reference (In2) is a fragmented
   3V3 island crossed by 13 traces. 2.8 mm length mismatch, 2 vias each, D-
   under H1's screw head. Uncoupled ≈130 Ω diff (target 90).
4. **J4 still a placeholder** (vertical THT vs the real right-angle SMD part).

## Should fix
- +3V3 fed only through 0.15 mm traces (In2 pour is 7 % of the board, eaten
  by the key-matrix bus); ~0.2 Ω to the far loads.
- MCU decoupling 7–14 mm from pins (target ~2 mm).
- USB_MCU_D- 0.1 mm from L1's switching pad.
- Y1 crystal: XOUT runs under the crystal, 14.75 mm + 3 vias to R4, XIN
  12 mm.
- +5V 0.3 mm everywhere (60–80 mm runs, part on an inner layer): ~0.1–0.15 V
  drop at 1 A.
- Stitching vias inside pads of assembled parts (Y1, J1, C4, C5): solder
  wicking.
- Hub decoupling 6–12 mm from VDD33; hub GND pin 14 on a 0.112 mm trace.
- USB_A1_D- under J2's shell; USB_A1 pair splits layers.

## Nice to have
Single-spoke thermals (Y1, Y2, C32); silkscreen cleanup; WS2812 pads are
1.27 mm pitch with 0.22 mm gaps (easy to bridge by hand); define the JLC
stack-up (JLC04161H-7628) for impedance control; USB-C VBUS/GND pad gap
0.1 mm (standard footprint).

## Verified OK
In1 GND plane solid (~90 % of the board, no traces); all geometry within
JLCPCB 4-layer limits (min track 0.112 mm, min clearance 0.10 mm); copper
≥0.3 mm from edges; vias tented; stitching ~2.5 mm pitch; USB_A2 pair
coupled on F.Cu (≈90 Ω est.).

## Plan
Critical nets first, by hand, locked; autorouter only for the rest (key
matrix, buttons, LEDs): EP via array; RPi-style regulator loop (C at
VREG_VIN, L1 and 4.7 µF at pins 62-65); per-pin decoupling routes; crystal
direct; USB_UP as a coupled F.Cu pair clear of H1; wide 5 V / 3V3 feeds;
keepouts under connector shells; stitching never inside pads.

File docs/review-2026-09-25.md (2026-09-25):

# Design review, 2026-09-25

An independent reviewer (a separate agent briefed as a senior EE, told to be
skeptical and to change nothing) checked the circuit against the datasheets:
RP2350 datasheet and hardware-design guide, the RPi minimal KiCad reference,
and the CH334, AMS1117, WS2812D, 1N4148W, EC12E, USB-C, USB-A, W25Q128JV,
ABM8 and AOTA inductor datasheets.

**Result:** no wiring errors. Every IC and connector pin landed on the right net.
The findings, and what was done about each:

| # | Finding | Severity | Resolution |
|---|---|---|---|
| 1 | Core-regulator inductor L1 would be placed reversed. RPi wants the polarity dot on +1V1; the easyeda2kicad footprint marks the dot on pad 2 | Should fix | **Fixed**: pad 2 now goes to +1V1. Check the dot in JLCPCB's placement preview |
| 2 | First WS2812 powered through a diode is marginal: VIH margin ~0 V at 5.25 V VBUS, and under-voltage at full white with a sagging VBUS | Should fix | **Fixed**: 2N7002 + 1 kΩ pull-up level shifter (Basic parts), all LEDs on 5 V. Data is inverted in firmware |
| 3 | AMS1117: 1.1–1.3 V dropout means brown-out on VBUS sag (hot-plug); only rated stable with tantalum caps | Should fix | **Fixed**: back to ME6211 (+1 Extended part) |
| 4 | 22 Ω instead of RPi's required 27 Ω USB series resistors | Should fix | **Accepted**: works at full speed; 27 Ω is an Extended part |
| 5 | ~76 µF on upstream VBUS (USB 2.0 allows 10 µF inrush); no fuse on the USB-A VBUS; CH334R reports self-powered | Should fix | **Accepted** for a hobby board: relies on the PC port's protection. Common in cheap hubs |
| 6 | CH334's 6 kV is HBM, not IEC 61000-4-2; USB-A ports get touched | Should fix | **Accepted** for now; USBLC6-2SC6 (C2827654) is the cheap upgrade |
| 7 | J4 lines 20–26 went to GPIO40–46, which aren't 5 V tolerant | Should fix | **Fixed**: moved to GPIO14–20 |
| 8 | Second 4.7 µF on +1V1 away from the LX loop | Nice to have | **Added** |
| 9 | RUN on a test pad for debug-probe reset | Nice to have | **Added** (TP5) |
| 10 | Encoder RC filter | Nice to have | Firmware debounce instead |
| 11 | RP2350-E9 (A2 stepping): pull-downs/floating inputs misbehave; **pull-ups are fine** | Info | Buttons, encoder and matrix all use pull-ups. Never scan the matrix with pull-downs |

Verified OK (highlights): RP2350B power/ground pins and ePad, VREG and crystal
circuits vs the RPi reference; CH334R all 16 pins, 3.3 V on V5 allowed
(§4.2), crystal load (internal ~16 pF, ~10 pF effective) matches the
ABM8-272-T3; flash, crystal, SOT-223/SOT-23 pin orders; USB-C both D± pairs
and 5.1 kΩ CC; USB-A pinout; WS2812 pin order vs footprint; tact switch pad
pairing; symbol pin numbers vs footprint pad numbers for every JLC part;
capacitor voltage ratings.

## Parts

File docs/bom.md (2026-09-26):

# Bill of materials

Generated by `hardware/scripts/bom.py` from the netlist, with live JLCPCB stock (re-run it before ordering).

- **JLCPCB assembles 58 parts**: 20 unique LCSC numbers, **6 Extended** (JLCPCB charges a loading fee per Extended part type, about $3 each), about **$7.24** per board
- **You solder 11 parts** (through-hole + 6x6 buttons), about **$1.65** per board from LCSC

## Assembled by JLCPCB

| Refs | Qty | Value | Part | LCSC | Type | Stock | Unit |
|---|---|---|---|---|---|---|---|
| C1, C9, C11 | 3 | 22u | CL21A226MAQNNNE | [C45783](https://jlcpcb.com/partdetail/C45783) | Basic | 4,253,741 | $0.2199 |
| C2, C7, C10, C12, C35, C36, C37, C105, C110, C115, C124, C129, C132, C141, C150, C151, C159, C160, C168, C169, C176, C300 | 22 | 100n | CL05B104KO5NNNC | [C1525](https://jlcpcb.com/partdetail/C1525) | Basic | 24,676,480 | $0.0045 |
| C3, C4, C5, C8, C190 | 5 | 10u | CL10A106KP8NNNC | [C19702](https://jlcpcb.com/partdetail/C19702) | Basic | 11,277,781 | $0.0319 |
| C6 | 1 | 1u | CL05A105KA5NQNC | [C52923](https://jlcpcb.com/partdetail/C52923) | Basic | 6,487,369 | $0.0099 |
| C161, C164, C165, C166 | 4 | 4.7u | CL05A475MP5NRNC | [C23733](https://jlcpcb.com/partdetail/C23733) | Basic | 2,581,692 | $0.0166 |
| C230, C231 | 2 | 15p | 0402CG150J500NT | [C1548](https://jlcpcb.com/partdetail/C1548) | Basic | 1,481,668 | $0.0038 |
| J1 | 1 | USB-C | TYPE-C-31-M-12 | [C165948](https://jlcpcb.com/partdetail/C165948) | Extended | 169,220 | $0.1855 |
| L1 | 1 | 3.3uH | AOTA-B201610S3R3-101-T | [C42411119](https://jlcpcb.com/partdetail/C42411119) | Extended | 8,095 | $0.2826 |
| Q1 | 1 | 2N7002 | 2N7002 | [C8545](https://jlcpcb.com/partdetail/C8545) | Basic | 1,763,228 | $0.0178 |
| R1, R2 | 2 | 5.1k | 0402WGF5101TCE | [C25905](https://jlcpcb.com/partdetail/C25905) | Basic | 6,639,200 | $0.0024 |
| R10, R231, R302, R303 | 4 | 1k | 0402WGF1001TCE | [C11702](https://jlcpcb.com/partdetail/C11702) | Basic | 8,639,907 | $0.0018 |
| R161 | 1 | 33 | 0402WGF330JTCE | [C25105](https://jlcpcb.com/partdetail/C25105) | Basic | 2,133,942 | $0.0035 |
| R266, R267 | 2 | 22 | 0402WGF220JTCE | [C25092](https://jlcpcb.com/partdetail/C25092) | Basic | 5,223,935 | $0.0027 |
| R301 | 1 | 10k | 0402WGF1002TCE | [C25744](https://jlcpcb.com/partdetail/C25744) | Basic | 23,695,868 | $0.0034 |
| SW6, SW7 | 2 | BOOTSEL | TS-1187A-B-A-B | [C318884](https://jlcpcb.com/partdetail/C318884) | Basic | 576,645 | $0.0205 |
| U1 | 1 | RP2350B | RP2350B | [C42415655](https://jlcpcb.com/partdetail/C42415655) | Extended | 4,271 | $1.2781 |
| U2 | 1 | CH334R | CH334R | [C4154405](https://jlcpcb.com/partdetail/C4154405) | Extended | 21,525 | $0.5603 |
| U3 | 1 | W25Q128JVS | W25Q128JVSIQ | [C97521](https://jlcpcb.com/partdetail/C97521) | Basic | 59,683 | $2.5496 |
| U4 | 1 | ME6211C33M5G-N | ME6211C33M5G-N | [C82942](https://jlcpcb.com/partdetail/C82942) | Extended | 178,470 | $0.0606 |
| Y1, Y2 | 2 | 12MHz | ABM8-272-T3 | [C20625731](https://jlcpcb.com/partdetail/C20625731) | Extended | 16,592 | $0.6188 |

## You solder (order these from LCSC)

Kept out of the JLCPCB BOM to skip their Extended-part fees. All are through-hole or big SMD pads.

| Refs | Qty | Value | Part | LCSC | Type | Stock | Unit |
|---|---|---|---|---|---|---|---|
| D1, D2, D3 | 3 | NUM (RGB) | WS2812D-F5-12mA-C1 | [C4154875](https://jlcpcb.com/partdetail/C4154875) | Extended | 319 | $0.2003 |
| ENC1 | 1 | EC12E24204A2 | EC12E24204A2 | [C351238](https://jlcpcb.com/partdetail/C351238) | Extended | 1,227 | $0.8640 |
| J2, J3 | 2 | USB-A 1 | AF 90 WJDG | [C456018](https://jlcpcb.com/partdetail/C456018) | Extended | 78,935 | $0.0439 |
| SW1, SW2, SW3, SW4, SW5 | 5 | Button 1 | KH-6X6X5H-STM | [C2837531](https://jlcpcb.com/partdetail/C2837531) | Extended | 606,271 | $0.0187 |

## Not ordered

- **J4** Key matrix flex (das4:FPC_Solder_1x26_P1.00mm)
- **TP1** TestPoint (TestPoint:TestPoint_Pad_D1.5mm)
- **TP2** TestPoint (TestPoint:TestPoint_Pad_D1.5mm)
- **TP3** TestPoint (TestPoint:TestPoint_Pad_D1.5mm)
- **TP4** TestPoint (TestPoint:TestPoint_Pad_D1.5mm)
- **TP5** TestPoint (TestPoint:TestPoint_Pad_D1.5mm)
- **TP6** TestPoint (TestPoint:TestPoint_Pad_D1.5mm)
- **TP7** TestPoint (TestPoint:TestPoint_Pad_D1.5mm)

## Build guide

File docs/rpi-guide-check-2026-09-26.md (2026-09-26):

# das4-controller vs "Hardware design with RP2350" (RP-008280-DS, release 3, 2026-08-20)

Source: the PDF from pip-assets.raspberrypi.com (25 pages), read in full, including the Appendix B RP2350B schematic (rendered at 400 dpi so I could read the pin numbers and the RUN/decoupling details). Design checked: `hardware/circuit/das4.py`, `critical.py`, and the routed `das4-controller.kicad_pcb`, measured with pcbnew in the `pcb` distrobox. Coordinates are board mm.

**Verdict: the circuit matches the guide. One cheap layout fix, plus one assembly-orientation check, before ordering.** Every RP2350B power, QSPI, crystal, USB, SWD and RUN pin lands on the same net as RPi's RP2350B minimal schematic, and the regulator parts are the exact values and parts RPi specifies. The FIX items are layout and assembly:
- DVDD pin 51 has no local 100 nF, and there is free room for one.
- The L1 polarity dot needs confirming at JLC, because the footprint carries two conflicting markers.

Scope note: the guide says nothing about errata (E9), 5 V tolerance or ADC-pin behaviour. Those come from the RP2350 datasheet. I note the design's handling of them below but can't grade it against this guide.

## Item-by-item

| Guide item (page / section) | What the guide says | What the design does | Status |
|---|---|---|---|
| Regulator parts (p.7, §2.1) | "C6, C7, and C9 - 4.7µF (0402)", "L1 - Abracon AOTA-B201610S3R3-101-T", "R3 - 33Ω" | C164 (VREG_VIN) 4.7 µF, C165 (+1V1) 4.7 µF, C161 (VREG_AVDD) 4.7 µF: all CL05A475 0402 X5R 10 V. L1 is the AOTA-B201610S3R3-101-T (C42411119). R161 is 33 Ω | OK |
| Regulator pin wiring (p.5 Fig.3, App.B) | VREG_VIN 64 to +3V3, LX 63 to L1, PGND 62 to GND, FB 65 to +1V1, AVDD 61 via 33 Ω/4.7 µF | Identical (checked on the board pads: 61 VREG_AVDD, 62 GND, 63 VREG_LX, 64 +3V3, 65 +1V1) | OK |
| Regulator layout (p.6–7, §2.1): "closely follow our layout", "if you choose not to use our example, then you do so at your own risk" | Order from the pins outward: CIN (C6), then COUT (C7), then L1, all parallel to the package edge. LX runs out between the cap pads; FB ties to +1V1 at C7; PGND "must connect to the main GND" so that switching currents return directly | Same order and handedness. C164 pad is 1.16 mm from pin 64; C165 is next; L1 is beyond, parallel to the edge. LX (4.75 mm) runs between the cap pads. FB is a Kelvin tap at C165. GND reaches main GND through one via pair (F.Cu pour keep-out). No copper under L1/LX on In1/In2/B.Cu. The only difference is a 4-layer stackup, and the rule areas follow the datasheet's 4-layer rule | OK |
| Inductor polarity (p.6–7, §2.1) | The dot must be "the right way round". In RPi's layout (Fig.4) the dot is on the **+1V1** pad | Netlist puts +1V1 on L1 pad 2, and the footprint's large silk dot (r 0.13 at 3.44, 23.1) is by pad 2. **But** the same easyeda footprint also has a small pin-1 marker circle at (1.54, 25.0), by pad 1 = VREG_LX. CPL rotation is 270°. If JLC orients the part by "pin 1", and Abracon's dot marks terminal 1 (as it does in RPi's footprint, where the dot pad is pad 1), the dot lands on LX: the wrong way round | **FIX** (verify) |
| VREG_AVDD filter (p.7, §2.1) | 33 Ω + 4.7 µF RC, because AVDD "is very sensitive to noise" | R161 33 Ω + C161 4.7 µF. C161 is 2.5 mm from pin 61 with its own GND via | OK |
| Input supply (p.7–8, §2.2) | LDO with the input/output caps its datasheet asks for (RPi: NCP1117, 10 µF + 10 µF) | ME6211C33, 10 µF in, 2×10 µF out, plus C190 10 µF bulk. Good for 500 mA | OK |
| Decoupling values/count (p.8, §2.2.1, Fig.6, App.B) | "100 nF capacitor per power pin". RPi's RP2350B uses 9×100 nF on +3V3 (ADC_AVDD shares IOVDD pin 60's cap; pins 68/69 share C12), 3×100 nF on +1V1, 10 µF bulk C19 | 11×100 nF on +3V3: one each on IOVDD 5/15/24/29/41/50/60/76, ADC_AVDD 59, USB_OTP_VDD 68, QSPI_IOVDD 69. 3×100 nF on DVDD 10/32/51. Plus 2×4.7 µF on +1V1 and 10 µF bulk. More than the reference | OK |
| Decoupling placement (p.8, §2.2.1) | "important to place decoupling close to the power pins". The only compromise RPi accepts is one cap shared by pins 68/69 | Close: pins 5 (2.4 mm), 10 (1.1), 41 (1.2), 59/60 (1.5–2.7), 64 (1.2). **Far** (pad to pad, straight line): pins 15 (20.6 mm), 69 (16.6), 24 (14.5), 29 (13.7), 76 (10.9), 68 (8.9), 50 (7.2). The +3V3 pins each have a via to the solid In2 plane, and 68/69 sit 2 mm from C164 (4.7 µF) on that plane, so these are acceptable. **DVDD** is weaker: +1V1 is a 0.5 mm B.Cu trace, not a plane. Pin 51's cap is 5.1 mm away (about 11 mm of trace). Pin 32's nearest cap is C110 at pin 10, about 11 mm of trace away. The F.Cu area directly above pin 51 (x 10.2–11.6, y 26.2–28.3) is **empty** apart from a GND stitching via at (10.95, 28.0) | +3V3: deviation-acceptable. DVDD 51: **FIX**. DVDD 32: deviation-acceptable (no room: R231/XOUT and the SWD/RUN escapes occupy it) |
| ADC_AVDD (App.B) | Tied to +3V3 (with IOVDD pin 60) | Tied to +3V3 with its own 100 nF (C159, 2.7 mm). ADC not used | OK |
| USB_OTP_VDD (App.B; p.8) | Tied to +3V3, cap shared with QSPI_IOVDD | Tied to +3V3. C168 is 8.9 mm away, but pin 68 has a plane via and C164 is 1.9 mm away | Deviation-acceptable |
| Flash part (p.10, §3.1; §3.3) | W25Q128JVS, 16 MB (the maximum). The bootrom needs 03h/02h/05h/06h/20h | W25Q128JVSIQ (C97521), the same part | OK |
| QSPI routing (p.10, §3.1) | "QSPI pins … should be wired directly to the flash, using short connections" | Direct, no series parts. SS 11.9 mm, SCLK 5.3, SD0 1.9, SD1 13.2, SD2 7.8 (2 vias), SD3 14.2 (2 vias). C300 100 nF about 1.9 mm from U3 VCC | OK |
| QSPI series resistors (p.10–11, §3.1–3.2) | None on the data lines. R9/R10 are 0 Ω links only for the RP2354/secondary-memory option | None; the option isn't needed on an RP2350B with one flash | OK |
| QSPI_SS pull-up (p.10) | R1 10 kΩ, DNF with the W25Q128JV, footprint kept "just in case" | R301 10 kΩ fitted, 2.4 mm from U3 pin 1. With the button pressed SS sits at about 0.3 V (10 k against 1 k), still a solid low | OK |
| BOOTSEL (p.10–11) | QSPI_SS → R6 1 kΩ → button → GND. "It is important to include resistor R6". R1/R6 "should be placed close to the flash chip" | R302 1 kΩ at U3 (about 2.8 mm from pin 1), then SW6 to GND. The USB_BOOT net behind R302 is 54 mm long with 2 vias. It's isolated by the 1 kΩ, so it's fine | OK |
| Crystal (p.13–14, §4, §4.1) | 12 MHz ABM8-272-T3: "We highly recommend using this crystal along with the accompanying circuitry" | ABM8-272-T3 (C20625731, Abracon, confirmed via JLC API) | OK |
| Load caps (p.13) | CL 10 pF. 15 pF each gives 7.5 pF + about 3 pF stray, about 10.5 pF | C230/C231 15 pF C0G (0402CG150J500NT). XIN 4.9 mm, XOUT_XTAL 6.4 mm, no vias. On the 4-layer board (In1 about 0.2 mm down) that adds roughly 0.5 pF per side, well inside the 3 pF allowance | OK |
| Series resistor (p.13) | R2 1 kΩ between XOUT and the crystal, for IOVDD = 3.3 V. Any deviation "will require extensive testing" | R231 1 kΩ, pin 31 → R231 → Y1.3/C231. IOVDD is 3.3 V | OK |
| XOSC startup (p.13–14) | Copy the circuit exactly, otherwise test start-up over temperature | Exact copy at 3.3 V. Keep the SDK default XOSC start-up delay: the guide gives no reason to change it | OK |
| USB series resistors (p.15, §5.1) | "require 27 Ω series termination resistors … placed close to the chip" | R266/R267 are **22 Ω** and sit at the **hub** end: (34.4, 28.5/29.7), about 1.7–2 mm from CH334R pins 3/4. The MCU side of each resistor is **52 mm (D+) and 42 mm (D−)** of trace, 2 vias each. 27 Ω 0402 is Extended at JLC (C25100, checked). This is an on-board, 12 Mbit/s link: 50 mm is about 0.3 ns against 4–20 ns FS edges, so the line is electrically short and placement doesn't matter. 22 vs 27 Ω shifts the source impedance by about 5 Ω. It will work, but it isn't what the guide says | Deviation-acceptable |
| USB pull-ups/downs (p.15) | None needed on the RP2350 side | None | OK |
| USB impedance (p.15) | 90 Ω differential over unbroken GND (2-layer 1 mm example) | The MCU link is FS and on-board only; the upstream pair was done at about 90 Ω on the 4-layer board (review 2) | OK |
| RUN button (p.18 §5.4; App.B) | RUN → SW2 → **R4 1 kΩ** → GND. No external pull-up, no cap | RUN → SW7 → R303 1 kΩ → GND. TP5 on RUN. RUN is 55 mm long with 2 vias, which is fine | OK |
| SWD (p.17–18, §5.3) | SWCLK/SWDIO brought out (header or JST) with GND | TP1 SWCLK, TP2 SWDIO, TP3 GND, TP4 3V3, TP5 RUN (bare pads, pogo/solder) | OK |
| GPIO assignment (App.B pinout) | QFN-80: GPIO40–47 are the ADC pins (53–60) | Checked pad by pad: GPIO42/43/45/46/47 → BTN5/4/1/2/3 (pins 53/54/56/57/58), GPIO44 → LED gate (pin 55), GPIO8/13 → ENC_B/A (pins 6/12), J4 → GPIO14–39. All match the RP2350B pinout | OK |
| GPIO default pulls (p.11, §3.2) | "the default state of GPIO0 is to be pulled low at power-up" (applies to all GPIO) | GPIO44 → 2N7002 gate is held off, so the WS2812 DIN idles high through its 1 kΩ to 5 V until firmware runs. Harmless. Buttons and encoder use internal pull-ups set by firmware | OK |
| Errata E9 / 5 V tolerance / ADC pins | **Not covered by this guide** | The design uses pull-ups only (per the RP2350 datasheet E9 note, no pull-down scanning). J4 stays on GPIO0–39. GPIO40–47 only see 3.3 V signals. Nothing on the board puts 5 V on a GPIO | n/a (not in guide) |
| Board tech (p.4, §1.3) | 2-layer, top-side-only, 0402 needed at 0.4 mm pitch | 4-layer, top-side assembly, 0402 | OK |

## FIX items

1. **Add a 100 nF on DVDD pin 51.**
   - **Now:** pin 51's nearest cap is C151, 5.1 mm away pad to pad and about 11 mm along the 0.5 mm B.Cu +1V1 spine. The guide wants one right at each power pin; RPi's only accepted compromise is one cap shared by pins 68/69.
   - **Where it fits:** the F.Cu area directly above the pin is free.
   - **Change:**
     - In `critical.py`/`gen_board.py`, move C151 (or add one more 100 nF) to about (10.8, 26.95), vertical, with pad 1 (+1V1) at y ≈ 26.47. Stub it straight to pin 51 (10.8, 25.91).
     - Put pad 2 (GND) at y ≈ 27.43, into the existing GND via at (10.95, 28.0) or a new one just above.
     - Re-run DRC afterwards.
   - **Pin 32:** there's no room beside it (R231 and the XOUT trace, the SWD/RUN escapes). I'd accept it; pin 10's cap is about 11 mm of trace away and pin 51's would then be local. If you ever move the crystal block 1 mm right, put a 100 nF at pin 32 too.

2. **Confirm the L1 dot lands on the +1V1 pad (pad 2, the end nearer U3/C165 at y = 23.0) before paying for assembly.**
   - **Why it's in doubt:** the easyeda footprint has a visible silk dot by pad 2, and also a small pin-1 circle by pad 1 (VREG_LX). JLC places by its library pin 1 and rotation (270° in `cpl.csv`). Nothing in the repo shows which terminal Abracon's dot marks. The guide makes this the one thing that "massively" affects the regulator.
   - **Change:**
     - Pull the AOTA-B201610S3R3-101-T drawing and see whether the dot marks terminal 1.
     - In JLC's DFM/placement preview, check the 3D model's dot is at the +1V1 pad.
     - If it isn't, flip the L1 rotation in the CPL by 180°. Don't re-wire.
     - Add an order note: "L1 polarity dot toward C165 (+1V1)".
     - Remove the contradicting marker from the footprint so the silk shows only the +1V1 dot.

## Deviations accepted (no change needed, listed so they're a conscious choice)

- USB series resistors are 22 Ω at the hub, not 27 Ω "close to the chip". It's electrically irrelevant for a 50 mm FS link, and 27 Ω is an Extended part. If you want strict compliance for free, swap R266/R267 onto the MCU end of the link: the 50 mm run is on B.Cu under U1, so they would go near pins 66/67 where space allows. Otherwise leave them.
- Several +3V3 caps sit 9–21 mm from their pins. This is acceptable because every +3V3 pin has its own via to the solid In2 plane, and the high-activity QSPI_IOVDD/USB_OTP_VDD pins sit 2 mm from C164 (4.7 µF). The refs (C115, C169, …) suggest one cap per pin, but the caps don't sit at their pins; don't read the refdes as meaning they're local.

## Not guide items, noticed in passing

- `docs/bom.md` is stale: it still lists an AMS1117, D4 1N4148W and old refs. `build/jlcpcb/bom.csv` is current (ME6211, R301/R302 etc.). Regenerate bom.md so nobody orders from the wrong one.
- In `bom.csv`, SW6 and SW7 are both commented "RESET" (SW6 is BOOTSEL). This is cosmetic.
- The .kicad_pcb still has no `(stackup)` section (thickness 1.6 mm). The USB_UP pair widths assume JLC04161H-7628, so choose it on the order form.

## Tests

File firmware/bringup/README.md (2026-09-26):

# Bring-up firmware (pico-sdk + TinyUSB)

A minimal test firmware for this board, used to prove the design can be
built for (see [../../docs/firmware-check-2026-09-26.md](../../docs/firmware-check-2026-09-26.md)).
It isn't the keyboard firmware yet. What it does:
- enumerates as a USB keyboard
- scans GPIO14–39 (J4) as a placeholder matrix, driving low and reading with pull-ups
- reads SW1 (GPIO45) and sets up the encoder pins
- drives the 3 WS2812s on GPIO44 with the output pad inverted (the 2N7002
  level shifter inverts the data)

Board header: `boards/` (RP2350B, 16 MB W25Q128, 12 MHz crystal).

## Build

Needs cmake, ninja, the Arm GNU toolchain (arm-none-eabi) and pico-sdk 2.x
(with the tinyusb submodule):

```sh
export PICO_SDK_PATH=/path/to/pico-sdk
cmake -S firmware/bringup -B build/fw -G Ninja
ninja -C build/fw          # -> build/fw/das4fw.uf2
```

## Serial console

Test pads TX (GPIO0), RX (GPIO1) and GND on the left tab are UART0, pico-sdk's
default stdio UART (115200 8N1). A 3.3 V USB-serial adapter there shows
`printf` output even when USB doesn't enumerate.

## Flash

Hold BOOTSEL, tap RESET (or plug in): the board shows up as a USB drive.
Copy `das4fw.uf2` onto it. Later, `picotool reboot -u` gets back there
without the button. SWD pads TP1–TP4 work with a Raspberry Pi Debug Probe.

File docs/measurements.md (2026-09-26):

# Measurements

Every mechanical number the board depends on, where it came from, and how sure
we are. All positions are in mm from the **bottom-left corner of the main
body**, +Y up. The USB-C end is the top and the knob end is the bottom, with
the component side facing you and the USB-A ports pointing right.

The same numbers live in [`hardware/scripts/gen_board.py`](../hardware/scripts/gen_board.py).
Change them there and regenerate.

**Source key:**
- **measured**: caliper/ruler on the real board
- **photo**: traced from a top-down photo scaled so the main body is 83.9 mm; expect ±1–2 mm
- **datasheet**: from the part's datasheet

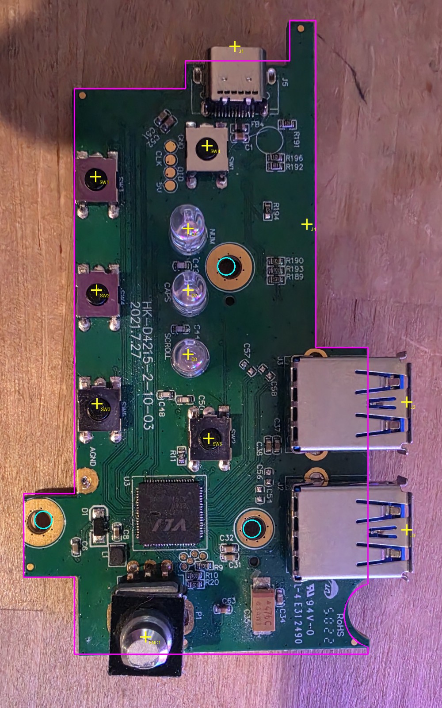
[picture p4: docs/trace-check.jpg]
Draft traced over the original board


*Magenta: outline. Cyan: mounting holes. Yellow: part centres, as used by the generator.*

## Outline

| What | Value | Source |
|---|---|---|
| Main body length (bottom edge → main top edge) | 83.9 ± 0.5 | measured |
| USB-C tab top | 88.0 | measured |
| Thin finger top | 94.0 | measured |
| Finger width | ~4 | measured |
| Main body width (left edge → J4 edge) | 35.9 | photo, probably the "36 mm" on the sketch |
| Width at the USB-A section | 43.6 | photo |
| USB-A section starts at y | 45.5 | photo |
| USB-C tab left edge x | 16.5 | photo |
| Finger left edge x | 32.0 | photo |
| Left mounting tab: sticks out to x | −7.55 | photo |
| Left mounting tab: y from–to | 11.4 – 23.8 (12.4 tall) | photo, probably the "12 mm" on the sketch |
| Notch on USB-A edge: opening length × depth | 9.35 × 3.5 | measured |
| Notch upper end y (near USB-A #2) | 10.4 (lower end ≈ 1.05) | photo |

## Mounting holes (all photo, M2.5 assumed)

| Hole | x | y |
|---|---|---|
| H1 (between LEDs and J4) | 22.6 | 57.5 |
| H2 (near USB-A) | 26.4 | 18.6 |
| H3 (left tab) | −4.6 | 19.9 |

## Parts that must line up with the case

| Part | x | y | Notes |
|---|---|---|---|
| J1 USB-C, mouth edge | 23.9 | 90.2 | Mouth sticks out ~2 mm past the tab (photo) |
| J2 USB-A #1, mouth edge | 49.4 | 37.4 | ~5.8 mm past the board edge (photo) |
| J3 USB-A #2, mouth edge | 49.4 | 18.4 | 19 mm port pitch (photo) |
| J4 key-matrix flex pads (bottom side) | 33.1 – 35.6 | 51 – 76.5 | 26 pads, 1.0 mm pitch (26 mm measured); flex soldered on, overlapping from the board edge |
| ENC1 volume encoder shaft | 10.0 | 5.8 | From the fit-check print (50 mm bar for scale): the body sits about flush with the bottom edge. The first photo trace (2.5) measured the shaft *tip*, which parallax shifted ~3 mm outward. Caliper check welcome |
| SW1 / SW2 / SW3 (left column) | 3.2 / 3.3 / 3.4 | 70.8 / 54.0 / 37.1 | photo |
| SW4 (by USB-C) | 19.7 | 75.4 | photo |
| SW5 (middle) | 20.0 | 32.0 | photo |
| D1 NUM / D2 CAPS / D3 SCROLL | 16.9 | 63.1 / 54.0 / 44.5 | 5 mm LEDs, ~9 mm tall (measured) |

## Heights (measured)

| Part | Height |
|---|---|
| USB-A | ~7 mm |
| LEDs | ~9 mm |
| Encoder body | 6 mm (matches Bourns PEC12R: 6.0 mm) |
| Encoder shaft | "14 mm". **To confirm:** from the PCB or from the top of the body? |
| Encoder collar | 7 mm diameter (matches PEC12R: 7.0 mm) |

## Still to measure

1. **Encoder:** shaft length from the PCB surface. Clicks: 5 per quarter turn, so 20 per full turn (confirm by counting a full turn). No push switch.
2. **Mounting holes:** real diameters and caliper positions.
3. Anything above that's marked *photo* and has to fit the case exactly: the USB port positions and the outline steps.

## Checking the fit

Print [`fit-check-1to1.pdf`](fit-check-1to1.pdf) at **100% / "Actual size"**, not "fit to page".
Measure the 50 mm bar first. If it's off, the printer scaled the page and nothing else on it is trustworthy.
Then lay the original board on the print and mark where it disagrees.

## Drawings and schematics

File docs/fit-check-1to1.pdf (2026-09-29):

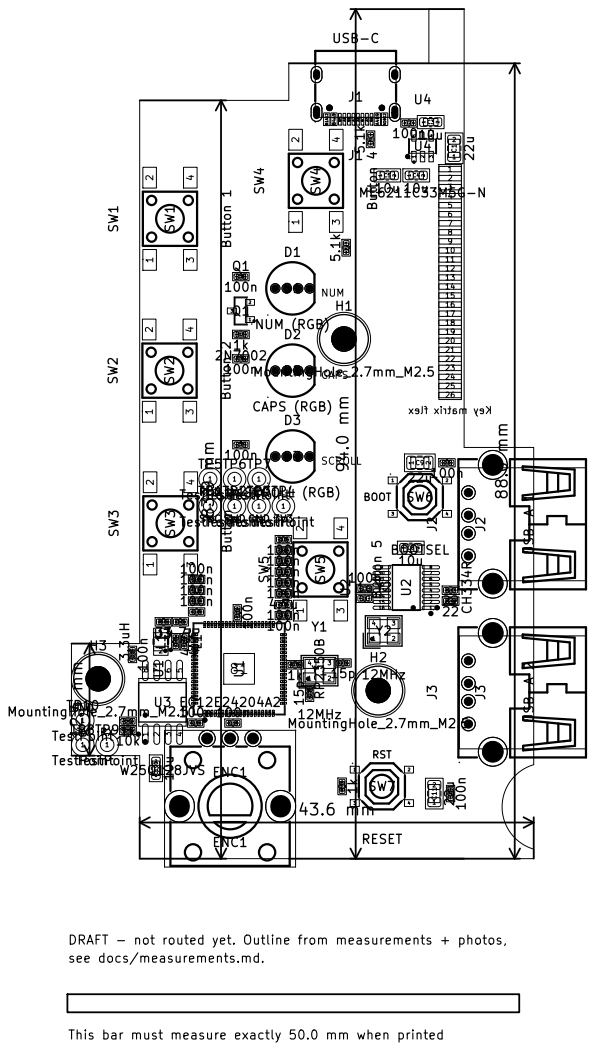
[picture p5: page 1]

DRAFT - not routed yet. Outline from measurements + photos, see docs/measurements.md. This bar must measure exactly 50.0 mm when printed

Size: A4 | Rev:
KiCad E.D.A. 10.0.5-unknown | Id: 1/1

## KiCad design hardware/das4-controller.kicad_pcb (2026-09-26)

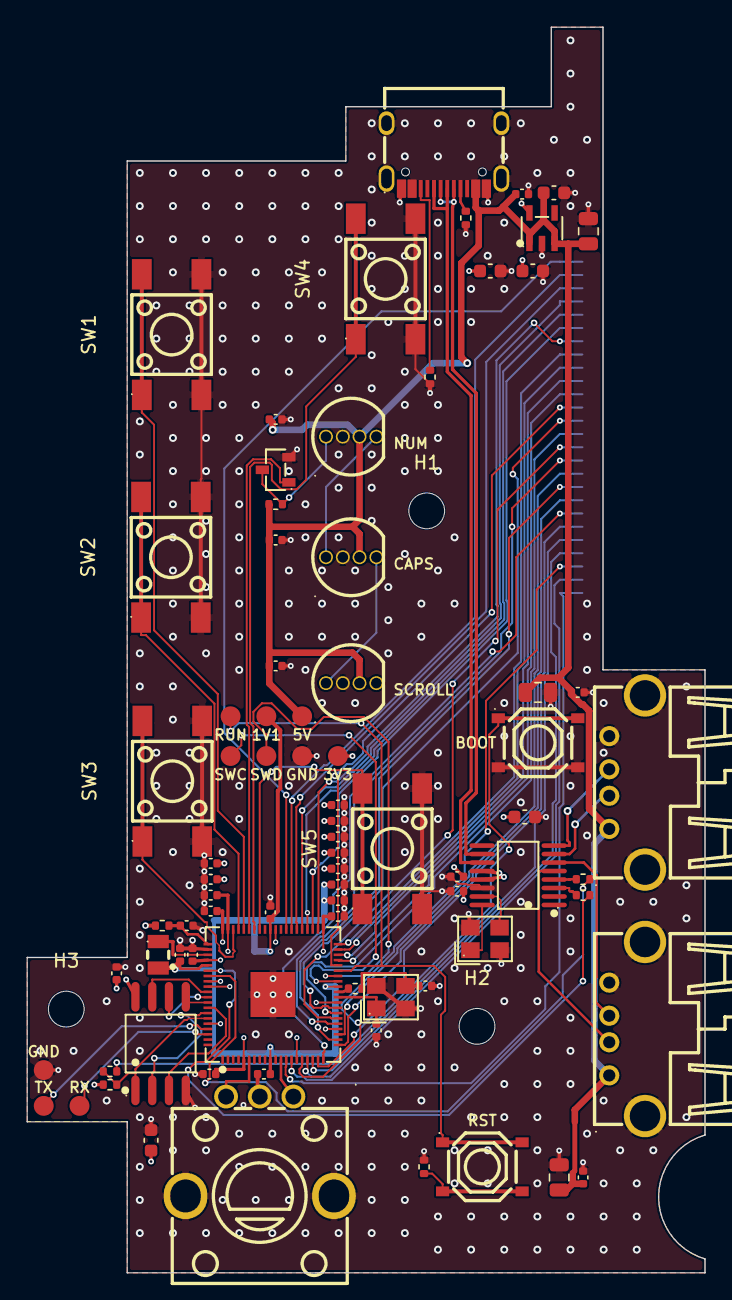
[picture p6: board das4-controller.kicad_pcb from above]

Board: 4 copper layers, 51.1 x 94.0 mm, 83 parts (1 on the bottom side), 73 nets.

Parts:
C1, C9, C11: 22u; C_0805_2012Metric
C2, C7, C10, C12, C35, C36, C37, C105, C110, C115, C124, C129, C132, C141, C150, C151, C159, C160, C168, C169, C176, C300: 100n; C_0402_1005Metric
C3, C4, C5, C8, C190: 10u; C_0603_1608Metric
C6: 1u; C_0402_1005Metric
C161, C164, C165, C166: 4.7u; C_0402_1005Metric
C230, C231: 15p; C_0402_1005Metric
D1: NUM (RGB); LED-TH_4P-BD5.8-P1.27_WS2812D-F5-12MA-C1
D2: CAPS (RGB); LED-TH_4P-BD5.8-P1.27_WS2812D-F5-12MA-C1
D3: SCROLL (RGB); LED-TH_4P-BD5.8-P1.27_WS2812D-F5-12MA-C1
ENC1: EC12E24204A2; SW-TH_EC12E24204A2
H1, H2, H3: MountingHole_2.7mm_M2.5
J1: USB-C; USB-C_SMD-TYPE-C-31-M-12_1
J2: USB-A 1; USB-A-TH_AF-WJDG
J3: USB-A 2; USB-A-TH_AF-WJDG
J4: Key matrix flex; FPC_Solder_1x26_P1.00mm
L1: 3.3uH; IND-SMD_L2.0-W1.6_AOTA-B201610S3R3-101-T
Q1: 2N7002; SOT-23-3_L2.9-W1.3-P1.90-LS2.4-BR
R1, R2: 5.1k; R_0402_1005Metric
R10, R231, R302, R303: 1k; R_0402_1005Metric
R161: 33; R_0402_1005Metric
R266, R267: 22; R_0402_1005Metric
R301: 10k; R_0402_1005Metric
SW1: Button 1; SW-SMD_4P-L6.0-W6.0-P4.50-LS9.0_H5.0
SW2: Button 2; SW-SMD_4P-L6.0-W6.0-P4.50-LS9.0_H5.0
SW3: Button 3; SW-SMD_4P-L6.0-W6.0-P4.50-LS9.0_H5.0
SW4: Button 4; SW-SMD_4P-L6.0-W6.0-P4.50-LS9.0_H5.0
SW5: Button 5; SW-SMD_4P-L6.0-W6.0-P4.50-LS9.0_H5.0
SW6: BOOTSEL; SW-SMD_4P-L5.1-W5.1-P3.70-LS6.5-TL_H1.5
SW7: RESET; SW-SMD_4P-L5.1-W5.1-P3.70-LS6.5-TL_H1.5
TP1, TP2, TP3, TP4, TP5, TP6, TP7, TP8, TP9, TP10: TestPoint; TestPoint_Pad_D1.5mm
U1: RP2350B; QFN-80_L10.0-W10.0-P0.40-TL-EP3.4
U2: CH334R; QSOP-16_L4.9-W3.9-P0.64-LS6.0-BL
U3: W25Q128JVS; SOIC-8_L5.3-W5.3-P1.27-LS8.0-BL
U4: ME6211C33M5G-N; SOT-23-5_L3.0-W1.7-P0.95-LS2.8-BL
Y1, Y2: 12MHz; CRYSTAL-SMD_4P-L3.2-W2.5-BL

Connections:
+1V1: C110.1, C132.1, C151.1, C165.1, C166.1, L1.2, TP6.1, U1.10, U1.32, U1.51, U1.65
+3V3: C4.1, C5.1, C6.1, C7.1, C8.1, C105.1, C115.1, C124.1, C129.1, C141.1, C150.1, C159.1, C160.1, C164.1, C168.1, C169.1, C176.1, C190.1, C300.1, R161.1, R301.1, TP4.1, U1.5, U1.15, U1.24, U1.29, U1.41, U1.50, U1.59, U1.60, U1.64, U1.68, U1.69, U1.76, U2.12, U2.13, U3.8, U4.5
+5V: C1.1, C2.1, C3.1, C9.1, C10.1, C11.1, C12.1, C35.1, C36.1, C37.1, D1.2, D2.2, D3.2, J1.A4B9, J2.1, J3.1, R10.1, TP7.1, U4.1, U4.3
BTN1: SW1.1, SW1.2, U1.56
BTN2: SW2.1, SW2.2, U1.57
BTN3: SW3.1, SW3.2, U1.58
BTN4: SW4.1, SW4.2, U1.54
BTN5: SW5.1, SW5.2, U1.53
ENC_A: ENC1.A, U1.12
ENC_B: ENC1.B, U1.6
GND: C1.2, C2.2, C3.2, C4.2, C5.2, C6.2, C7.2, C8.2, C9.2, C10.2, C11.2, C12.2, C35.2, C36.2, C37.2, C105.2, C110.2, C115.2, C124.2, C129.2, C132.2, C141.2, C150.2, C151.2, C159.2, C160.2, C161.2, C164.2, C165.2, C166.2, C168.2, C169.2, C176.2, C190.2, C230.2, C231.2, C300.2, D1.3, D2.3, D3.3, ENC1.C, ENC1.D, ENC1.E, J1.1, J1.2, J1.3, J1.4, J1.A1B12, J1.B1A12, J2.4, J2.5, J3.4, J3.5, Q1.2, R1.2, R2.2, R303.2, SW1.3, SW1.4, SW2.3, SW2.4, SW3.3, SW3.4, SW4.3, SW4.4, SW5.3, SW5.4, SW6.3, SW6.4, TP3.1, TP10.1, U1.62, U1.81, U2.14, U3.4, U4.2, Y1.2, Y1.4, Y2.2, Y2.4
KM1: J4.1, U1.48
KM2: J4.2, U1.47
KM3: J4.3, U1.46
KM4: J4.4, U1.45
KM5: J4.5, U1.44
KM6: J4.6, U1.43
KM7: J4.7, U1.42
KM8: J4.8, U1.40
KM9: J4.9, U1.39
KM10: J4.10, U1.38
KM11: J4.11, U1.37
KM12: J4.12, U1.36
KM13: J4.13, U1.28
KM14: J4.14, U1.27
KM15: J4.15, U1.26
KM16: J4.16, U1.25
KM17: J4.17, U1.23
KM18: J4.18, U1.22
KM19: J4.19, U1.21
KM20: J4.20, U1.20
KM21: J4.21, U1.19
KM22: J4.22, U1.18
KM23: J4.23, U1.17
KM24: J4.24, U1.16
KM25: J4.25, U1.14
KM26: J4.26, U1.13
LED_DATA_N: Q1.1, U1.55
LED_DIN1: D1.4, Q1.3, R10.2
LED_DIN2: D1.1, D2.4
LED_DIN3: D2.1, D3.4
unnamed: J1.A5, R1.1
unnamed: J1.B5, R2.1
unnamed: U2.16, Y2.1
unnamed: U2.15, Y2.3
unnamed: R231.1, U1.31
unnamed: R267.2, U1.67
unnamed: R266.2, U1.66
unnamed: TP1.1, U1.33
unnamed: TP2.1, U1.34
unnamed: TP8.1, U1.77
unnamed: TP9.1, U1.78
QSPI_SCLK: U1.71, U3.6
QSPI_SD0: U1.72, U3.5
QSPI_SD1: U1.74, U3.2
QSPI_SD2: U1.73, U3.3
QSPI_SD3: U1.70, U3.7
QSPI_SS: R301.2, R302.1, U1.75, U3.1
RUN: SW7.1, SW7.2, TP5.1, U1.35
RUN_BTN: R303.1, SW7.3, SW7.4
USB_A1_D+: J2.3, U2.8
USB_A1_D-: J2.2, U2.7
USB_A2_D+: J3.3, U2.6
USB_A2_D-: J3.2, U2.5
USB_BOOT: R302.2, SW6.1, SW6.2
USB_MCU_D+: R267.1, U2.4
USB_MCU_D-: R266.1, U2.3
USB_UP_D+: J1.A6, J1.B6, U2.11
USB_UP_D-: J1.A7, J1.B7, U2.10
VREG_AVDD: C161.1, R161.2, U1.61
VREG_LX: L1.1, U1.63
XIN: C230.1, U1.30, Y1.1
XOUT_XTAL: C231.1, R231.2, Y1.3

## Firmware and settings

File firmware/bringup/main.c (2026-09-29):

#include "pico.h"
_Static_assert(NUM_BANK0_GPIOS == 48, "B package");
_Static_assert(PICO_FLASH_SIZE_BYTES == 16*1024*1024, "16MB");
// Minimal bring-up firmware for das4-controller (RP2350B).
// - USB HID keyboard via TinyUSB (enumerates behind the CH334R hub)
// - Key matrix: 26 lines GPIO14..39 (J4 pad k -> GPIO 40-k); demo scans
//   col lines as outputs-low, row lines as inputs with pull-UP (E9-safe).
// - SW1 on GPIO45 (ADC pin used as digital input, pull-up)
// - 3x WS2812D on GPIO44 through an inverting 2N7002 -> pad output inverted.
#include <stdio.h>
#include "pico/stdlib.h"
#include "hardware/pio.h"
#include "hardware/clocks.h"
#include "hardware/gpio.h"
#include "hardware/platform_defs.h"
#include "tusb.h"
#include "ws2812.pio.h"

#define N_LEDS 3
#define MATRIX_FIRST 14
#define MATRIX_LAST  39
// Placeholder split until the key PCB is mapped: 8 "rows" (inputs) + 18 "cols".
#define N_ROWS 8
static const uint row_pins[N_ROWS] = {39, 38, 37, 36, 35, 34, 33, 32};
#define N_COLS 18
static const uint col_pins[N_COLS] = {31,30,29,28,27,26,25,24,23,22,21,20,19,18,17,16,15,14};
static bool keys[N_ROWS][N_COLS];

static PIO led_pio; static uint led_sm; static uint led_off;

static void ws2812_init(void) {
    // GPIO44 >= 32: PIO must be given a GPIO base of 16 (covers 16..47).
    bool ok = pio_claim_free_sm_and_add_program_for_gpio_range(
        &ws2812_program, &led_pio, &led_sm, &led_off, DAS4_LED_DATA_PIN, 1, true);
    hard_assert(ok);
    pio_sm_config c = ws2812_program_get_default_config(led_off);
    sm_config_set_sideset_pins(&c, DAS4_LED_DATA_PIN);
    sm_config_set_out_shift(&c, false, true, 24);
    sm_config_set_fifo_join(&c, PIO_FIFO_JOIN_TX);
    int cycles = ws2812_T1 + ws2812_T2 + ws2812_T3;
    sm_config_set_clkdiv(&c, clock_get_hz(clk_sys) / (800000.0f * cycles));
    pio_gpio_init(led_pio, DAS4_LED_DATA_PIN);
    pio_sm_set_consecutive_pindirs(led_pio, led_sm, DAS4_LED_DATA_PIN, 1, true);
    // The 2N7002 + 1k pull-up to 5 V inverts: invert at the pad so the PIO
    // program stays standard. Idle (PIO low) -> pad high -> FET on -> DIN low = reset.
    gpio_set_outover(DAS4_LED_DATA_PIN, GPIO_OVERRIDE_INVERT);
    pio_sm_init(led_pio, led_sm, led_off, &c);
    pio_sm_set_enabled(led_pio, led_sm, true);
}

static void ws2812_put(uint8_t r, uint8_t g, uint8_t b) {
    pio_sm_put_blocking(led_pio, led_sm, ((uint32_t)g << 24) | ((uint32_t)r << 16) | ((uint32_t)b << 8));
}

static void matrix_init(void) {
    for (uint i = 0; i < N_ROWS; i++) {
        gpio_init(row_pins[i]); gpio_set_dir(row_pins[i], GPIO_IN); gpio_pull_up(row_pins[i]);
    }
    for (uint i = 0; i < N_COLS; i++) {
        // Unselected columns are hi-Z (input, pull-up) so no ghost paths drive.
        gpio_init(col_pins[i]); gpio_set_dir(col_pins[i], GPIO_IN); gpio_pull_up(col_pins[i]);
        gpio_put(col_pins[i], 0);
    }
}

static void matrix_scan(void) {
    for (uint c = 0; c < N_COLS; c++) {
        gpio_set_dir(col_pins[c], GPIO_OUT);           // drive low
        busy_wait_us_32(5);
        uint64_t all = gpio_get_all64();               // GPIO0..47
        for (uint r = 0; r < N_ROWS; r++) keys[r][c] = !((all >> row_pins[r]) & 1);
        gpio_set_dir(col_pins[c], GPIO_IN);            // release (pull-up)
    }
}

static void hid_task(bool sw1) {
    static bool last_any = false;
    if (!tud_hid_ready()) return;
    uint8_t kc[6] = {0}; uint n = 0;
    if (sw1) kc[n++] = HID_KEY_A;
    for (uint r = 0; r < N_ROWS && n < 6; r++)
        for (uint c = 0; c < N_COLS && n < 6; c++)
            if (keys[r][c]) kc[n++] = HID_KEY_B;
    bool any = n > 0;
    if (any || last_any) tud_hid_keyboard_report(0, 0, any ? kc : NULL);
    last_any = any;
}

int main(void) {
    stdio_init_all();
    printf("\ndas4-controller bring-up firmware\n");
    tusb_init();
    matrix_init();
    gpio_init(DAS4_BTN1_PIN); gpio_set_dir(DAS4_BTN1_PIN, GPIO_IN); gpio_pull_up(DAS4_BTN1_PIN);
    gpio_init(DAS4_ENC_A_PIN); gpio_pull_up(DAS4_ENC_A_PIN);
    gpio_init(DAS4_ENC_B_PIN); gpio_pull_up(DAS4_ENC_B_PIN);
    ws2812_init();
    uint32_t t = 0;
    while (true) {
        tud_task();
        matrix_scan();
        bool sw1 = !gpio_get(DAS4_BTN1_PIN);
        static bool last_sw1;
        if (sw1 != last_sw1) {
            printf("SW1 %s\n", sw1 ? "down" : "up");
            last_sw1 = sw1;
        }
        hid_task(sw1);
        if (to_ms_since_boot(get_absolute_time()) - t > 50) {
            t = to_ms_since_boot(get_absolute_time());
            for (int i = 0; i < N_LEDS; i++) ws2812_put(sw1 ? 64 : 0, sw1 ? 0 : 16, 0);
        }
    }
}

// TinyUSB callbacks
uint16_t tud_hid_get_report_cb(uint8_t i, uint8_t id, hid_report_type_t t, uint8_t *b, uint16_t l) { return 0; }
void tud_hid_set_report_cb(uint8_t i, uint8_t id, hid_report_type_t t, uint8_t const *b, uint16_t l) {
    // Lock-LED report from host (NUM/CAPS/SCROLL) arrives here.
}

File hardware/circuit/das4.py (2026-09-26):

#!/usr/bin/env python3
"""das4-controller circuit, written with SKiDL.

    make netlist        # -> hardware/das4-controller.net

Block diagram:

    USB-C (to PC) -> CH334R USB 2.0 hub -> USB-A port 1  (J2)
                                         -> USB-A port 2  (J3)
                                         -> RP2350B       (port 3; port 4 unused)

    RP2350B GPIO -> 26 x key matrix (J4), 5 buttons, encoder A/B, 3 lock LEDs

Every JLCPCB-assembled part carries its LCSC number in the "LCSC" field, which
ends up in the BOM. Parts come from:
  - hardware/lib/jlc.kicad_sym  (fetched from LCSC with easyeda2kicad, so
    symbol pins and footprint pads always agree)
  - KiCad's stock "Device" library for plain Rs, Cs and LEDs
References:
  - RP2350 core: Raspberry Pi "Hardware design with RP2350" minimal design
  - Hub: WCH CH334/CH335 datasheet v2.91, section 6.1 (bus powered)
"""
import os
import sys

from skidl import (KICAD9, Net, Part, generate_netlist, lib_search_paths,
                   set_default_tool)

HERE = os.path.dirname(os.path.abspath(__file__))
HW = os.path.dirname(HERE)
JLC = os.path.join(HW, "lib", "jlc.kicad_sym")

set_default_tool(KICAD9)  # KiCad 10 uses the same library format
lib_search_paths[KICAD9].append(os.environ.get("KICAD_SYMBOL_DIR", "/usr/share/kicad/symbols"))

# ---------------------------------------------------------------------------
# GPIO assignment. Any RP2350 GPIO can do any of these jobs, so this table is
# the only thing to change when layout wants a different pin order.
# J4 pin k -> GPIO(40 - k): pin 1 -> GPIO39 ... pin 26 -> GPIO14. That order
# follows the RP2350B's pins round the package, and J4's pins run in order
# too, so the 26 lines fan out to J4 without crossing each other. It also
# keeps them off GPIO40-47, which (unlike GPIO0-39) are not 5 V tolerant.
J4_GPIO = [40 - k for k in range(1, 27)]
# Buttons and the LED data line sit on GPIO42-47. Those are the RP2350B's
# ADC pins (not 5 V tolerant), which is fine for buttons/LED but keeps J4 on
# 5 V-tolerant pins. With U1 rotated 90 degrees on the board they face up,
# towards the buttons.
BUTTON_GPIO = [45, 46, 47, 43, 42]     # SW1..SW5
# encoder either side of DVDD pin 10's cap, straight down to its pins
ENC_A_GPIO, ENC_B_GPIO = 13, 8
LED_DATA_GPIO = 44                     # WS2812 chain: NUM -> CAPS -> SCROLL
# UART0 debug pads: GPIO0 (TX), GPIO1 (RX). Spare: GPIO2-7, GPIO9-12, GPIO40-41

# ---------------------------------------------------------------------------
R0402 = "Resistor_SMD:R_0402_1005Metric"
C0402 = "Capacitor_SMD:C_0402_1005Metric"
C0603 = "Capacitor_SMD:C_0603_1608Metric"
C0805 = "Capacitor_SMD:C_0805_2012Metric"

# value -> LCSC basic parts (all checked in stock, see docs/bom.md)
RES = {"0": "C17168", "22": "C25092", "33": "C25105", "330": "C25104",
       "1k": "C11702", "5.1k": "C25905", "10k": "C25744"}
CAP = {"100n": ("C1525", C0402), "1u": ("C52923", C0402), "4.7u": ("C23733", C0402),
       "15p": ("C1548", C0402), "10u": ("C19702", C0603), "22u": ("C45783", C0805)}


def lcsc(part, code):
    part.fields["LCSC"] = code
    return part


def hand(part):
    """Soldered by hand: kept out of the JLCPCB BOM/CPL (no Extended fee).
    The LCSC number stays so docs/bom.md can list what to buy."""
    part.fields["Assembly"] = "hand"
    return part


def jlc(name, ref=None, code=None, value=None):
    p = Part(JLC, name, ref=ref) if ref else Part(JLC, name)
    if value:
        p.value = value
    if code:
        lcsc(p, code)
    return p


def R(value, a, b, ref=None):
    kw = {"ref": ref} if ref else {}
    p = lcsc(Part("Device", "R", value=value, footprint=R0402, **kw), RES[value])
    p[1] += a
    p[2] += b
    return p


def C(value, a, b=None, ref=None):
    code, fp = CAP[value]
    kw = {"ref": ref} if ref else {}
    p = lcsc(Part("Device", "C", value=value, footprint=fp, **kw), code)
    p[1] += a
    p[2] += b if b is not None else gnd
    return p


# ---------------------------------------------------------------------------
gnd = Net("GND")
vbus = Net("+5V")          # from the PC, via USB-C
v33 = Net("+3V3")
v11 = Net("+1V1")          # RP2350 core, from its on-chip switching regulator

# --- USB-C upstream --------------------------------------------------------
usb_up_dp, usb_up_dm = Net("USB_UP_D+"), Net("USB_UP_D-")
j1 = jlc("TYPE-C-31-M-12", "J1", "C165948", "USB-C")
# Only the A4/B9 VBUS pair is wired: B4/A9 sits boxed in by SW4's leg with no
# room to escape. A USB-C plug ties all four VBUS contacts together, so either
# orientation reaches A4/B9 (2 contacts, ~1.25 A each: plenty here).
vbus += j1["A4B9"]
gnd += j1["A1B12"], j1["B1A12"], j1["EH"]
usb_up_dp += j1["A6"], j1["B6"]
usb_up_dm += j1["A7"], j1["B7"]
R("5.1k", j1["A5"], gnd)   # CC1/CC2 pull-downs: we're a USB device (UFP)
R("5.1k", j1["B5"], gnd)
C("22u", vbus)
C("100n", vbus)


# No separate ESD chips: the CH334R has 6 kV ESD protection on all its USB
# pins (datasheet, features), and the RP2350B sits behind the hub.


# --- 3.3 V regulator (hub + MCU + flash, ~150-200 mA) ------------------------
# ME6211: ~0.1 V dropout and stable with ceramic caps. (An AMS1117 would be a
# Basic part but drops out when VBUS sags, e.g. hot-plugging a USB-A device,
# which would brown out the hub and MCU; design review 2026-09-25.)
ldo = jlc("ME6211C33M5G-N", "U4", "C82942")
vbus += ldo["VIN"], ldo["CE"]
gnd += ldo["VSS"]
v33 += ldo["VOUT"]
C("10u", vbus)
C("10u", v33)
C("10u", v33)

# --- CH334R USB 2.0 hub ------------------------------------------------------
# Powered from 3.3 V on both V5 and VDD33 (datasheet 6.1: cooler, and our LDO
# is there anyway). XI/XO have built-in ~16 pF load caps: no external caps.
hub = jlc("CH334R", "U2", "C4154405")
v33 += hub["V5"], hub["VDD33"]
gnd += hub["GND"]
usb_up_dm += hub["DMU"]
usb_up_dp += hub["DPU"]
C("1u", hub["V5"])
C("100n", hub["VDD33"])
C("10u", hub["VDD33"])
xh = jlc("ABM8-272-T3_C20625731", "Y2", "C20625731", "12MHz")
hub["XI"] += xh[1]
hub["XO"] += xh[3]
gnd += xh[2], xh[4]
# RESET#/CDP left open (internal pull-up), port 4 unused

# --- USB-A downstream ports --------------------------------------------------
# VBUS straight from the PC's 5 V: the PC's port already limits current, so
# no polyfuses (they're JLCPCB Extended parts).
for ref, n, dm, dp in (("J2", 1, "DM1", "DP1"), ("J3", 2, "DM2", "DP2")):
    port_dp, port_dm, port_vbus = Net(f"USB_A{n}_D+"), Net(f"USB_A{n}_D-"), vbus
    j = hand(jlc("AF90-WJDG", ref, "C456018", f"USB-A {n}"))
    # pins: 1 VCC, 2 D-, 3 D+, 4 GND, 5 shield
    port_vbus += j[1]
    gnd += j[4], j[5]
    port_dp += j[3], hub[dp]
    port_dm += j[2], hub[dm]
    C("22u", port_vbus)
    C("100n", port_vbus)
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

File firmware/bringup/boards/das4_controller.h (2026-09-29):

// Board header for das4-controller (RP2350B QFN-80, W25Q128JV 16 MB, 12 MHz XOSC)
#ifndef _BOARDS_DAS4_CONTROLLER_H
#define _BOARDS_DAS4_CONTROLLER_H

pico_board_cmake_set(PICO_PLATFORM, rp2350)

// QFN-80 package: 48 GPIO. Must be 0 for the B package.
#define PICO_RP2350A 0

// UART0 debug console on the TX/RX test pads (left tab): stdio goes here, so
// printf works even when USB doesn't enumerate. 115200 8N1, 3.3 V levels.
#define PICO_DEFAULT_UART 0
#define PICO_DEFAULT_UART_TX_PIN 0
#define PICO_DEFAULT_UART_RX_PIN 1
#define PICO_DEFAULT_LED_PIN_INVERTED 0

// W25Q128JV: same QSPI boot2 as the Pico 2 / PGA2350
#define PICO_BOOT_STAGE2_CHOOSE_W25Q080 1
#ifndef PICO_FLASH_SPI_CLKDIV
#define PICO_FLASH_SPI_CLKDIV 2
#endif
pico_board_cmake_set_default(PICO_FLASH_SIZE_BYTES, (16 * 1024 * 1024))
#ifndef PICO_FLASH_SIZE_BYTES
#define PICO_FLASH_SIZE_BYTES (16 * 1024 * 1024)
#endif

// 12 MHz ABM8-272-T3 is the SDK default XOSC frequency; stated for clarity.
#define XOSC_HZ 12000000u

// Board-specific pins
#define DAS4_LED_DATA_PIN 44
#define DAS4_BTN1_PIN     45
#define DAS4_ENC_A_PIN    13
#define DAS4_ENC_B_PIN    8

#endif

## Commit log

2026-09-24 Draft board outline and part placement for Das Keyboard 4 Pro controller
    Mechanical first pass for an RP2350B replacement controller board:
    - Board outline, mounting holes and placeholder footprints for USB-C,
    2x USB-A, 26-pin key-matrix connector, volume encoder, 5 buttons and
    3 lock LEDs, generated from measurement tables in gen_board.py
    - Positions traced from a top-down photo scaled to the measured
    83.9 mm body; 88/94 mm steps line up within photo accuracy
    - Design notes (architecture, 37-GPIO budget, part candidates),
    measurement log with sources, 1:1 fit-check PDF and renders
    - CI builds everything in the same KiBot/KiCad 10 container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
    [das4-controller.kicad_pcb]
2026-09-24 Fix USB-A edge notch: 9.35 mm opening, 3.5 mm deep
    Measured on the fit-check print: the notch is a shallow arc, not the
    6.6 mm half circle traced from the photo. Keep its upper end near USB-A
    port 2 and extend it toward the bottom corner, leaving ~1 mm of board.
    [das4-controller.kicad_pcb]
2026-09-24 Render boards with 3D models and add an angled view
    Point renders at the KiCad Flatpak 3D model library (overridable via
    KICAD10_3DMODEL_DIR), use high quality with shadows, and add a
    perspective render to the README. Drop the stray "REF**" silkscreen
    text that some library footprints carry.
    [das4-controller.kicad_pcb]
2026-09-24 Move volume encoder to its real position
    The first photo trace located the top of the ~20 mm shaft, which
    parallax shifted ~3 mm outward. Measured on the fit-check print against
    the 50 mm scale bar, the body sits about flush with the bottom edge:
    shaft centre (10.0, 5.8) instead of (10.6, 2.5).
    [das4-controller.kicad_pcb]
2026-09-24 Use a no-switch encoder; knob has 20 detents and doesn't push
    The original knob doesn't press, and a push-switch encoder can't fit:
    with the body flush against the board edge its switch pins would land
    off the board. Swap to the no-switch footprint, drop the encoder push
    from the GPIO budget (36 pins) and record 20 detents per turn.
    [das4-controller.kicad_pcb]
2026-09-24 Circuit in SKiDL, JLCPCB parts, and a placed 4-layer board
    The circuit is now code (hardware/circuit/das4.py) and every part is a
    real, in-stock JLCPCB part:
    - RP2350B core copied from Raspberry Pi's minimal design (crystal, QSPI
    flash, 1.1 V regulator inductor, decoupling, BOOTSEL/RESET, SWD pads)
    - CH334R USB 2.0 hub: USB-C upstream, two USB-A ports and the MCU
    downstream, powered from 3.3 V per the WCH datasheet; ESD on every
    port, polyfuses on the USB-A VBUS lines
    - ME6211 3.3 V LDO, Alps EC12E no-switch encoder, 5 buttons, three
    5 V-driven lock LEDs, 26 key-matrix lines to GPIO21-46
    The board is generated from the netlist: measured mechanical parts stay
    put, everything else is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
    [das4-controller.kicad_pcb]
2026-09-24 Make the lock LEDs RGB (WS2812D-F5)
    Swap the three white LEDs and their 2N7002/330R drivers for WS2812D-F5
    addressable RGB LEDs in the same 5 mm through-hole shape, so the colour
    is set in firmware. One GPIO (GPIO11) drives the chain NUM -> CAPS ->
    SCROLL through a 74AHCT1G125 level shifter (the LEDs want a 5 V data
    signal) and a 33R series resistor; 100 nF per LED. Frees GPIO12/13.
    [das4-controller.kicad_pcb]
2026-09-25 Cut JLCPCB Extended parts from 15 to 5; add order-file export
    Swap to JLCPCB Basic parts where it's safe and move the easy parts to
    hand soldering, so only the RP2350B, CH334R, USB-C, inductor and crystal
    carry Extended fees:
    - AMS1117-3.3 instead of ME6211; 22R instead of 27R USB resistors
    - drop the USBLC6 ESD chips (the CH334R has 6 kV ESD on its USB pins)
    and the USB-A polyfuses (the PC's port limits current)
    - drive the WS2812 chain with the first LED powered through a 1N4148W,
    instead of a 74AHCT level shifter
    - Basic TS-1187A BOOTSEL/RESET buttons
    - USB-A, encoder, LEDs and the 6x6 buttons are marked Assembly=hand:
    out of the JLCPCB BOM/CPL, listed separately in docs/bom.md
    `ma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
    [das4-controller.kicad_pcb]
2026-09-25 Route the board: 0 unconnected, 0 real DRC violations
    Circuit (from the design review):
    - inductor L1 polarity per RPi (dot to +1V1); ME6211 back instead of
    AMS1117 (VBUS-sag brown-out); 2N7002 + 1k pull-up level shifter for the
    WS2812 chain (inverted data); second 4.7 uF on +1V1; RUN test pad
    - J4 pin k -> GPIO(40-k): follows the package pin order so the 26-line
    bus fans out without crossings, and stays off non-5V-tolerant GPIO40-47
    - USB-C: only the A4/B9 VBUS pair wired (B4/A9 is boxed in by SW4; plugs
    tie all VBUS contacts together)
    Routing (make route): 4-layer F.Cu / In1 GND plane / In2 signals + 3V3
    pour / B.Cu signals + GND pour. Freerouting runs 4 variants in parallel
    and k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
    [das4-controller.kicad_pcb]
2026-09-25 Re-layout the MCU corner per the layout review, re-route
    U1 rotated 90 degrees; the critical nets are now drawn by hand in
    hardware/scripts/critical.py and locked before autorouting, following
    Raspberry Pi's minimal-design layout:
    - core regulator block at pins 61-65 (VREG_VIN/+1V1 caps at the pins, LX
    between their pads into L1, GND vias, VREG_AVDD RC filter)
    - 3x3 via array in the exposed GND pad
    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
    [das4-controller.kicad_pcb]
2026-09-25 Fix layout review 2: keep-outs, DVDD cap, EP paste, re-route
    - Rule areas: no copper on In1/In2/B.Cu under L1 and VREG_LX (RP2350
    datasheet 6.3.8); no F.Cu pour round the regulator block (GND at one
    point); no F.Cu tracks/vias under the USB-A shells; 2.5 mm clear round
    the mounting holes; router-only keep-out round the crystal block
    - +1V1 spine leaves under U1's left pad row (clear of L1/LX and the QSPI
    flash gap)
    - C110 right under DVDD pin 10; encoder moved to GPIO13 (A) / GPIO8 (B)
    - EP: 5 vias in a "+" with 4 paste windows between them (~50 %)
    - decap columns at 1.2 mm pitch so shared GND vias clear the pads; plane
    fanout vias never touch their own pad
    - LX enters L1 from outs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
    [das4-controller.kicad_pcb]
2026-09-26 J4: solder pads for the key PCB's 26-way 1.0 mm flex; re-route
    The key PCB's flex cable ("CON2") is hot-bar soldered at both ends, so J4
    is now 26 SMD pads (0.6 x 2.5 mm, 1.0 mm pitch) on the bottom side at the
    board edge, hand-soldered like the original: no connector, no cost.
    Keys only on the other end (no lights), so no 5 V check is needed.
    Also:
    - TP6/TP7 test pads for +1V1 and +5V (bring-up)
    - router-only via band 0.5 mm round the USB_UP pair (layout review 2)
    - a pre-placed via at each J4 pad so lines can arrive on either layer
    - route.py cleanup: an unused via is removed and the track ends that met
    on it are linked inside its disc; zero-length tracks dropped
    - route_best: 6 variant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
    [das4-controller.kicad_pcb]
2026-09-26 Check against RPi's "Hardware design with RP2350"; cap at DVDD pin 51
    docs/rpi-guide-check-2026-09-26.md: section-by-section check of the
    circuit and layout against the guide. Circuit matches RPi's reference
    (regulator parts/values, flash, crystal, RUN/BOOTSEL/SWD, pinout).
    - C151 moved right above DVDD pin 51 with its own GND via
    - L1 orientation confirmed: JLC's library model has the polarity dot on
    pad 2 = +1V1, as in RPi's layout (Abracon datasheet + guide Fig. 4)
    - docs/design.md: "Ordering at JLCPCB" (stackup, L1 dot check, hand parts)
    - docs/bom.md regenerated (was stale); bom.csv lists both values when
    refs share a part (SW6 BOOTSEL / SW7 RESET)
    0 unconnected, 0 non-cosmetic DRC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
    [das4-controller.kicad_pcb]
2026-09-26 Firmware check: pico-sdk bring-up firmware builds for this pinout
    docs/firmware-check-2026-09-26.md: firmware options vs this board.
    pico-sdk + TinyUSB supports everything today; KMK/CircuitPython works
    with a custom board def; QMK has no RP2350 support yet. No hardware
    change needed. firmware/bringup: a minimal test firmware (matrix scan,
    SW1, inverted WS2812 on GPIO44) that builds to a .uf2.
    Fix the LED note: invert the GPIO44 pad, not WS2812_EXTERNAL_PULLUP.
    [das4.py, das4_controller.h, main.c]
2026-09-26 UART0 debug pads, silkscreen tidy, re-route
    - TP8/TP9/TP10 on the left tab: UART0 TX (GPIO0), RX (GPIO1), GND, a
    serial console for bring-up (firmware check suggestion)
    - silkscreen: references only on SW1-SW5 and J4; the rest on F.Fab so
    nothing prints over neighbouring parts. Test pads get function labels
    (SWC, SWD, GND, 3V3, RUN, 1V1, 5V, TX, RX), SW6/SW7 read BOOT/RST
    - route.py: trim_dangling() removes signal-track dead ends after the via
    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
    [das4-controller.kicad_pcb]
2026-09-29 Add AGENTS.md/CLAUDE.md, plan doc, pretest/check scripts; UART stdio in bring-up firmware
    - AGENTS.md: pipeline, where things live, design rules, lessons, KiCad 10
    Python quirks, review process (CLAUDE.md imports it)
    - docs/plan.md: status, history, next steps, bring-up and firmware plan,
    accepted deviations
    - make pretest (hand layout DRC before routing), make check (post-route
    checks DRC can't do): hardware/scripts/pretest.py, check_layout.py
    - fp-lib-table: add the das4 library (J4 flex pads) so KiCad finds it
    - firmware/bringup: printf over UART0 (TX/RX pads), SW1 events; builds
    with 0 warnings
    - README: current status, QMK not yet supported, docs/reviews links,
    stackup in the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
    [das4_controller.h, main.c]
